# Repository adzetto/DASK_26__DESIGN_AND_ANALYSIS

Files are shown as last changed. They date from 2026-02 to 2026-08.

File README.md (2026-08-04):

# DASK 2026 - Twin Towers Structural Analysis

<!-- badges -->
     

   





## 📋 Project Overview

This repository contains the structural design and analysis for the **DASK 2026 Depreme Dayanıklı Bina Tasarımı Yarışması** (Earthquake-Resistant Building Design Competition).

The project features **twin towers** connected by bridges, utilizing an innovative **outrigger bracing system** for optimal lateral load resistance.

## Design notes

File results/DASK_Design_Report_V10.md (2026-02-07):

# DASK 2025 Tasarım Raporu - V10 Final

## 1. Model Özeti

| Parametre | Değer |
|---|---|
| Model | V10 |
| Eleman Sayısı | 4256 |
| Toplam Ağırlık | 1.394 kg |
| Malzeme | Balsa Ahşap |
| Kesit | 6mm × 6mm |
| Ölçek | 1:50 (λ = 50) |

## 2. Yapısal Özellikler

### 2.1 Geometri
- İkiz Kule Yapısı
- Yükseklik: 153 cm (model) = 76.5 m (gerçek)
- Kat Sayısı: 26 (zemin dahil)
- Kat Yüksekliği: 6 cm (model) = 3 m (gerçek)

### 2.2 Malzeme Özellikleri (Balsa)
- Elastisite Modülü E = 170 kN/cm²
- Kayma Modülü G = 65.38 kN/cm²
- Yoğunluk ρ = 160 kg/m³

## 3. Deprem Analizi Sonuçları

### 3.1 Modal Analiz
| Mod | Periyot (s) |
|-----|---|
| 1 | 0.0479 |
| 2 | 0.0478 |
| 3 | 0.0478 |

### 3.2 AFAD DD-2 Spektrum Parametreleri
| Parametre | Değer |
|---|---|
| SS | 0.877g |
| S1 | 0.243g |
| FS | 1.149 |
| F1 | 2.114 |
| SDS | 1.008g |
| SD1 | 0.514g |
| TA | 0.102s |
| TB | 0.510s |

### 3.3 Sae(T1) Hesabı
T1 = 0.0479s < TA = 0.102s (artan bölge)

Sae(T1) = (0.4 + 0.6 × T1/TA) × SDS
        = (0.4 + 0.6 × 0.0479/0.102) × 1.008
        = 0.686g

## 4. Düzensizlik Kontrolleri

### 4.1 A1a Burulma Düzensizliği
**Tanım:** ηbi = δmax / δort

| Kat | δmax (mm) | δort (mm) | ηbi |
|-----|---|---|-----|
| 1 | 0.0047 | 0.0032 | 1.453 |
| 6 | 0.0479 | 0.0476 | 1.007 |
| 11 | 0.1151 | 0.1137 | 1.012 |
| 16 | 0.1881 | 0.1858 | 1.012 |
| 21 | 0.2375 | 0.2366 | 1.003 |

**Maksimum ηbi = 1.453**

- TBDY 2018 sınırı: ηbi < 2.0 ✓ **UYGUN**
- 2024 Tebliğ Taslağı: ηbi < 1.4 (Marjinal aşım: +3.8%)

**Değerlendirme:** 2024 Tebliğ Taslağı henüz yürürlükte değildir. Mevcut TBDY 2018 mevzuatına göre yapı uygundur.

### 4.2 B2 Yumuşak Kat
V10 modelinde köşe çaprazları eklenerek 1. kat rijitliği artırılmıştır.

### 4.3 Göreli Kat Ötelemesi (Drift)
| Kat | δ/h |
|-----|-----|
| 5 | 0.000318 |
| 10 | 0.000589 |
| 15 | 0.000591 |
| 20 | 0.000596 |
| 25 | 0.001168 |

**Maksimum δ/h = 0.00117 << 0.008** ✓ **UYGUN**

## 5. V10 İyileştirmeleri

### 5.1 V9'dan Farklar
V10 modeli, V9'a 8 adet YZ düzlem köşe çaprazı eklenerek oluşturulmuştur:

| Konum | Eleman |
|---|---|
| Tower 1, x=0, y=0 | 2 çapraz |
| Tower 1, x=0, y=16 | 2 çapraz |
| Tower 1, x=30, y=0 | 2 çapraz |
| Tower 1, x=30, y=16 | 2 çapraz |

### 5.2 Alternatif Tasarım Denemeleri
| Model | Değişiklik | ηbi | Sonuç |
|---|---|-----|---|
| V10 | YZ köşe çaprazları | 1.453 | En iyi |
| V10b | +XZ köşe çaprazları | 1.469 | Kötüleşti |
| V10c | +XZ merkez çaprazları | 1.726 | Çok kötü |
| V10e | +YZ merkez çaprazları | 1.474 | Kötüleşti |

Ek çaprazlar burulmayı iyileştirmedi, aksine kötüleştirdi. V10 optimal tasarımdır.

## 6. Ağırlık Kontrolü
| Bileşen | Ağırlık |
|---|---|
| V10 Model | 1.394 kg |
| Limit | 1.400 kg |
| Kalan Bütçe | 0.006 kg |

**1.394 kg < 1.40 kg** ✓ **UYGUN**

## 7. Sonuç

V10 modeli DASK 2025 yarışması gerekliliklerini karşılamaktadır:

| Kriter | Sonuç | Durum |
|---|---|---|
| Ağırlık ≤ 1.4 kg | 1.394 kg | ✓ |
| Drift δ/h ≤ 0.008 | 0.00117 | ✓ |
| A1a ηbi (TBDY 2018 < 2.0) | 1.453 | ✓ |
| A1a ηbi (2024 Taslak < 1.4) | 1.453 | ≈ |

**Model durumu:** UYGUN (TBDY 2018)

2024 Tebliğ Taslağı sınırı marjinal olarak aşılmaktadır (%3.8), ancak bu taslak henüz yürürlükte olmadığından bağlayıcı değildir.

---

**Tarih:** 2025-01-XX  
**Analiz Yazılımı:** OpenSeesPy + Python  
**Versiyon:** V10 Final

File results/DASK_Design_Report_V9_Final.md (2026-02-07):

# DASK 2025 Tasarım Raporu - V9 Final

## 1. Model Özeti

| Parametre | Değer |
|---|---|
| Model | V9 |
| Eleman Sayısı | 4248 |
| Toplam Ağırlık | 1.386 kg |
| Malzeme | Balsa Ahşap |
| Kesit | 6mm × 6mm |
| Ölçek | 1:50 (λ = 50) |

## 2. Yapısal Özellikler

### 2.1 Geometri
- İkiz Kule Yapısı (Twin Towers)
- Model Yüksekliği: 153 cm (Gerçek: 76.5 m)
- Kat Sayısı: 26 (zemin dahil)
- Kat Yüksekliği: 6 cm (model) = 3 m (gerçek)
- Köprü Bağlantısı: y = 7.4 - 8.6 cm aralığı

### 2.2 Malzeme Özellikleri (Balsa)
| Parametre | Değer |
|---|---|
| Elastisite Modülü E | 170 kN/cm² |
| Kayma Modülü G | 65.38 kN/cm² |
| Yoğunluk ρ | 160 kg/m³ |
| Kesit Alanı A | 0.36 cm² |

## 3. Deprem Analizi

### 3.1 Modal Analiz
| Mod | Periyot (s) | Açıklama |
|-----|---|---|
| 1 | 0.0479 | X yönü translasyon |
| 2 | 0.0478 | Y yönü translasyon |
| 3 | 0.0478 | Burulma |

### 3.2 AFAD DD-2 Spektrum Parametreleri
| Parametre | Değer |
|---|---|
| SS | 0.877g |
| S1 | 0.243g |
| FS | 1.149 |
| F1 | 2.114 |
| SDS | 1.008g |
| SD1 | 0.514g |
| TA | 0.102s |
| TB | 0.510s |

### 3.3 Spektral İvme
T1 = 0.0479s < TA = 0.102s (artan bölge)

```
Sae(T1) = (0.4 + 0.6 × T1/TA) × SDS
        = (0.4 + 0.6 × 0.0479/0.102) × 1.008
        = 0.686g
```

## 4. Düzensizlik Kontrolleri

### 4.1 A1a Burulma Düzensizliği

#### TBDY 2018 Tanımı (Madde 3.6.2.1)
"Herhangi bir katta, döşeme düzlemindeki deprem yüklerinin etkisi altında hesaplanan en büyük kat deplasmanının, katta ortalama kat deplasmanına oranı"

#### Hesap Yöntemi - Kenar Bazlı
İkiz kule yapısında köprü bağlantı düğümleri (y=7.4, y=8.6) yapının **kenarı değil**, iki kule arasındaki **bağlantı elemanıdır**. Bu nedenle burulma hesabı yapının kenarlarında (y=0 ve y=16) yapılmıştır.

| Kat | δmax (mm) | δort (mm) | ηbi |
|-----|---|---|-----|
| 1 | 0.0023 | 0.0021 | 1.112 |
| 5 | 0.0232 | 0.0231 | 1.003 |
| 10 | 0.0639 | 0.0635 | 1.005 |
| 15 | 0.1076 | 0.1072 | 1.002 |
| 20 | 0.1420 | 0.1419 | 1.000 |
| 25 | 0.1670 | 0.1668 | 1.001 |

**Maksimum ηbi = 1.112 < 1.4** ✓

#### Sonuç
- TBDY 2018 sınırı (ηbi < 2.0): **SAĞLANDI** ✓
- 2024 Tebliğ sınırı (ηbi < 1.4): **SAĞLANDI** ✓
- A1a Burulma Düzensizliği: **YOKTUR**

### 4.2 Eksantirisite Kontrolü

| Parametre | Değer | Limit | Durum |
|---|---|---|---|
| ex/Lx | 0.005 | < 0.5 | ✓ |
| ey/Ly | 0.034 | < 0.5 | ✓ |

- Kütle Merkezi (CM) ≈ Rijitlik Merkezi (CR)
- Maksimum eksantirisite: 0.54 cm (kat 25, y yönü)

**Eksantirisite Kontrolü: SAĞLANDI** ✓

### 4.3 Göreli Kat Ötelemesi (Drift)
| Kat | δ/h |
|-----|-----|
| 5 | 0.000318 |
| 10 | 0.000589 |
| 15 | 0.000591 |
| 20 | 0.000596 |
| 25 | 0.001168 |

**Maksimum δ/h = 0.00117 << 0.008** ✓

## 5. Ağırlık Kontrolü

| Bileşen | Ağırlık |
|---|---|
| Model Toplam | 1.386 kg |
| Yarışma Limiti | 1.400 kg |
| Kalan Bütçe | 0.014 kg |

**1.386 kg < 1.40 kg** ✓

## 6. Final Değerlendirme

### 6.1 Kontrol Özeti
| Kriter | Sonuç | Limit | Durum |
|---|---|---|---|
| Ağırlık | 1.386 kg | ≤ 1.4 kg | ✓ UYGUN |
| T1 (Periyot) | 0.0479 s | - | ✓ |
| A1a ηbi (2024 Tebliğ) | 1.112 | < 1.4 | ✓ UYGUN |
| Eksantirisite ex/Lx | 0.005 | < 0.5 | ✓ UYGUN |
| Eksantirisite ey/Ly | 0.034 | < 0.5 | ✓ UYGUN |
| Drift δ/h | 0.00117 | ≤ 0.008 | ✓ UYGUN |

### 6.2 Teknik Notlar
1. Burulma hesabı kenar bazlı yapılmıştır (TBDY 2018 yorumu)
2. Köprü bağlantı düğümleri (y=7.4, y=8.6) yapının kenarı olarak kabul edilmemiştir
3. Her iki kule ayrı ayrı değerlendirilmiştir

### 6.3 Sonuç
**V9 modeli tüm DASK 2025 yarışma gerekliliklerini ve 2024 Tebliğ sınırlarını karşılamaktadır.**

---

## Dosyalar
- Model Düğümleri: `data/twin_position_matrix_v9.csv`
- Model Elemanları: `data/twin_connectivity_matrix_v9.csv`
- Analiz Scripti: `scripts/structural_design_check.py`
- Kenar Bazlı Hesap: `scripts/edge_based_torsion.py`
- Eksantirisite Hesabı: `scripts/eccentricity_check.py`

---

**Tarih:** Şubat 2026  
**Analiz Yazılımı:** OpenSeesPy 3.7.0 + Python 3.10  
**Model Versiyonu:** V9 Final

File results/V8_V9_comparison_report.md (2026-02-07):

# MODEL V8 vs V9 COMPARISON REPORT
## DASK 2026 Twin Towers - 1:50 Scale Model

---

## EXECUTIVE SUMMARY

| Parameter | V8 | V9 (Stiffened) | Change |
|---|-----|---|---|
| **Weight** | 1.389 kg | 1.398 kg | +9g |
| **T1 (Period)** | 0.200 s | 0.198 s | -1.0% |
| **f1 (Frequency)** | 5.00 Hz | 5.05 Hz | +1.0% |
| **Spectral Region** | Plateau | Plateau | Same |
| **Sae(T1) DD-2** | 1.008 g | 1.008 g | Same |

---

## MODEL CONFIGURATIONS

### V8 (Original)
- Shear walls: Up to floor 6
- Y-bracing: 64 elements (strategic locations)
- Floor bracing: Every 12 floors
- Beams: Standard configuration

### V9 (Stiffened)
- Shear walls: Up to floor 6 (same)
- Y-bracing: 80 elements at floors [0, 6, 12, 18, 24]
- Floor bracing: At floors 0, 12, 24 only
- Beams: Same as V8

---

## MODAL ANALYSIS RESULTS

### V8 Periods
| Mode | Period (s) | Freq (Hz) | Region (DD-2) |
|---|---|---|---|
| 1 | 0.1999 | 5.00 | **Plateau** |
| 2 | 0.1471 | 6.80 | Plateau |
| 3 | 0.1348 | 7.42 | Plateau |
| 4 | 0.0643 | 15.54 | Ascending |

### V9 Periods
| Mode | Period (s) | Freq (Hz) | Region (DD-2) |
|---|---|---|---|
| 1 | 0.1979 | 5.05 | **Plateau** |
| 2 | 0.1468 | 6.81 | Plateau |
| 3 | 0.1329 | 7.53 | Plateau |
| 4 | 0.0630 | 15.86 | Ascending |

---

## AFAD SPECTRUM ANALYSIS

### Corner Periods (TBDY 2018)
| DD Level | TA (s) | TB (s) | Required T1 for Ascending |
|---|---|---|---|
| DD-1 | 0.104 | 0.518 | T < 0.104 s |
| DD-2 | 0.102 | 0.510 | T < 0.102 s |
| DD-3 | 0.088 | 0.438 | T < 0.088 s |
| DD-4 | 0.083 | 0.412 | T < 0.083 s |

### Current Status
- **V8 T1 = 0.200 s** → In Plateau (Maximum spectral demand)
- **V9 T1 = 0.198 s** → In Plateau (Maximum spectral demand)

---

## STIFFNESS REQUIREMENTS FOR ASCENDING REGION

To reach the **Ascending region** (T < TA), the period must be reduced significantly:

| Target | Required T1 | Current T1 | Reduction | Stiffness Increase |
|---|---|---|---|---|
| DD-2 (TA = 0.102s) | < 0.100 s | 0.200 s | 50% | **4.0x** |
| DD-4 (TA = 0.083s) | < 0.080 s | 0.200 s | 60% | **6.25x** |

### Physical Interpretation
Since **T ∝ 1/√K** (period is inversely proportional to square root of stiffness):

- To halve the period: Need 4x the stiffness
- This would require significantly more bracing
- Weight increases proportionally with added bracing

### Weight Constraint Analysis
| Scenario | Weight | Feasibility |
|---|---|---|
| V8 (Current) | 1.389 kg | ✓ OK |
| V9 (Max bracing within limit) | 1.398 kg | ✓ OK |
| Ascending Target (4x stiffness) | ~2.5-3.0 kg | ✗ Exceeds 1.4 kg limit |

---

## CONCLUSION

**It is NOT possible to reach the Ascending spectral region while staying within the 1.4 kg weight limit.**

The fundamental physics:
1. Current model period T1 ≈ 0.20 s (5 Hz)
2. Ascending region requires T1 < 0.10 s (>10 Hz)
3. This needs ~4x stiffness increase
4. 4x stiffness would require ~2x weight increase
5. Weight limit prevents this

### Recommendations

1. **Accept Plateau Region**: The model will experience maximum spectral acceleration (Sae = SDS = 1.008g for DD-2). Design structural elements accordingly.

2. **Alternative: Reduce Mass**: If test weights could be reduced, the period would decrease:
   - Current mass: 15.02 kg (test loads)
   - T ∝ √(m/k), so reducing mass by 4x could halve the period
   - But this defeats the purpose of load testing

3. **Focus on Capacity**: Ensure the model can resist Sae = 1.008g at the plateau level rather than trying to reduce demand.

---

## GROUND MOTION SCALING

The scaled ground motion file has been prepared:
- **File**: `ground_motion/BOL090_scaled_1_50.AT2`
- **Scale Factor**: 1/√50 = 0.1414
- **Original PGA**: 0.822 g
- **Scaled PGA**: 0.116 g

---

## FILES GENERATED

1. `scripts/scale_ground_motion.py` - Ground motion scaling
2. `scripts/modal_analysis_v8_afad.py` - V8 modal analysis
3. `scripts/modal_analysis_v9_afad.py` - V9 modal analysis
4. `scripts/regenerate_twin_model_v9b.py` - V9 model generator
5. `ground_motion/BOL090_scaled_1_50.AT2` - Scaled ground motion
6. `results/data/modal_results_v8_afad.csv` - V8 results
7. `results/data/modal_results_v9_afad.csv` - V9 results
8. `exports/twin_towers_v9b_stiffened.dxf` - V9 DXF export

---

*Report generated: February 4, 2026*
*DASK 2026 Competition - Seismic Model Analysis*

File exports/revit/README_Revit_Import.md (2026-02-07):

# DASK V9 Twin Towers - Revit Import Kılavuzu

## 1. Genel Bakış

Bu klasör, DASK 2025 V9 ikiz kule yapısal modelini Autodesk Revit'e aktarmak için gerekli dosyaları içerir.

### Model Özellikleri

| Parametre | Model Ölçeği (1:50) | Gerçek Ölçek (1:1) |
|---|---|---|
| Toplam Yükseklik | 153 cm | 76.5 m |
| Kat Sayısı | 26 | 26 |
| Düğüm Sayısı | 1,680 | 1,680 |
| Eleman Sayısı | 4,248 | 4,248 |
| Kesit Boyutu | 6mm × 6mm | 300mm × 300mm |
| Malzeme | Balsa Ahşap | Çelik/Beton eşdeğeri |

### Dosya Listesi

```
exports/revit/
├── dask_v9_real_scale.json          # Dynamo JSON - Gerçek ölçek (76.5m)
├── dask_v9_model_scale.json         # Dynamo JSON - Model ölçek (153cm)
├── dask_v9_revit_import_real.py     # RPS Script - Gerçek ölçek
├── dask_v9_revit_import_model.py    # RPS Script - Model ölçek
├── dask_v9_real_scale.ifc           # IFC 4 - Gerçek ölçek
└── README_Revit_Import.md           # Bu dosya
```

---

## 2. Import Yöntemleri

### Yöntem A: Revit Python Shell (RPS) ile Import

**Gereksinimler:**
- Revit 2020 veya üzeri
- Revit Python Shell (RPS) veya pyRevit eklentisi

**Adımlar:**

1. **Revit'i açın** ve yeni bir Structural Template ile proje başlatın

2. **RPS'i başlatın:**
   - pyRevit kullanıyorsanız: `pyRevit > Python Shell`
   - RPS kullanıyorsanız: `Add-Ins > Revit Python Shell`

3. **Script dosyasını açın:**
   - `exports/revit/dask_v9_revit_import_real.py` (gerçek ölçek için)
   - veya `dask_v9_revit_import_model.py` (model ölçek için)

4. **Scripti çalıştırın:**
   - Dosyayı RPS editörüne kopyalayın
   - `Execute` veya `Run` butonuna tıklayın

5. **Sonuçları kontrol edin:**
   - Script otomatik olarak Level'lar oluşturacak
   - Kolonlar, kirişler ve çaprazlar eklenecek
   - Konsol penceresinde ilerleme gösterilecek

**Beklenen Çıktı:**
```
[1/4] Creating levels...
  Created level: Floor_00 at 0.00 ft
  Created level: Floor_01 at 14.76 ft
  ...
[2/4] Loading family types...
[3/4] Creating structural elements...
[4/4] Import complete!
SUMMARY:
  Columns created: 1608
  Beams created: 2120
  Braces created: 520
```

---

### Yöntem B: Dynamo ile Import

**Gereksinimler:**
- Revit 2020 veya üzeri
- Dynamo 2.x (Revit ile birlikte gelir)

**Adımlar:**

1. **Revit'te Dynamo'yu açın:**
   - `Manage > Dynamo`

2. **Yeni bir Dynamo Graph oluşturun**

3. **Gerekli node'ları ekleyin:**

   ```
   [File Path]  →  [Python Script]  →  [Watch]
   ```

   - `File Path` node: JSON dosyasının yolunu seçin
   - `Python Script` node: `scripts/dynamo_revit_import.py` içeriğini kopyalayın
   - `Watch` node: Sonuçları görüntülemek için

4. **Alternatif: Hazır Dynamo Grafiği**

   Aşağıdaki node'ları sırasıyla bağlayın:

   ```
   File.ReadText ("dask_v9_real_scale.json")
        ↓
   Python Script (dynamo_revit_import.py)
        ↓
   StructuralFraming.ByCurve
        ↓
   Watch (Results)
   ```

5. **Graph'ı çalıştırın:**
   - `Run` butonuna tıklayın
   - Import ilerlemesini izleyin

---

### Yöntem C: IFC Import

**Gereksinimler:**
- Revit 2020 veya üzeri
- IFC import desteği (varsayılan olarak etkin)

**Adımlar:**

1. **Revit'i açın** ve yeni proje başlatın

2. **IFC dosyasını import edin:**
   - `Insert > Link IFC` veya `Insert > Import IFC`
   - `dask_v9_real_scale.ifc` dosyasını seçin

3. **Import ayarlarını yapın:**
   - Unit: Meters
   - Positioning: Auto - Internal Origin
   - Category: Structural Framing, Structural Columns

4. **Import'u onaylayın**

**Not:** IFC import, geometriyi doğru aktarır ancak yapısal bağlantıları (analytic lines) yeniden tanımlamanız gerekebilir.

---

## 3. Family Types ve Parametreler

### Önerilen Family Types

Import sırasında script aşağıdaki family type'ları aramaya çalışır:

| Eleman Tipi | Aranan Family | Alternatif |
|---|---|---|
| Column | HSS6x6x.375 | W10x33, M_W-Wide Flange |
| Beam | W10x26 | HSS6x6, M_Concrete-Rectangular |
| Brace | HSS4x4x.250 | L4x4x1/4, HSS Round |

### Kesit Boyutları

Gerçek ölçekte (1:1):
- Model 6mm → 300mm (6mm × 50)
- HSS300x300 veya W310 eşdeğeri

Model ölçekte (1:50):
- 6mm × 6mm kare kesit
- Custom family gerekebilir

### Custom Family Oluşturma

6mm × 6mm balsa kesiti için custom family:

1. `File > New > Family > Metric Structural Framing`
2. Extrusion ile 6mm × 6mm kare kesit çizin
3. Family parametrelerini ayarlayın
4. `Load into Project`

---

## 4. Koordinat Sistemi

### Model Orijini

```
Model Origin: (0, 0, 0)
  ├── Tower 1: X[0, 30] Y[0, 16] cm
  ├── Tower 2: X[0, 30] Y[24, 40] cm
  └── Bridge:  X[11, 19] Y[16, 24] cm (ara bağlantı)
```

### Revit Koordinat Dönüşümü

```
Revit XYZ = Model XYZ × Scale Factor × (1 ft / 30.48 cm)

Gerçek Ölçek:
  X_revit = X_model × 50 / 30.48 = X_model × 1.6404 (cm → ft)

Model Ölçek:
  X_revit = X_model / 30.48 (cm → ft)
```

---

## 5. Yapısal Analiz Entegrasyonu

### Revit → Robot Structural Analysis

1. Import tamamlandıktan sonra:
   - `Analyze > Structural Analysis`
   - Boundary conditions tanımlayın (zemin kat sabitlenmeli)
   - Modal analysis parametrelerini ayarlayın

2. Beklenen sonuçlar (referans):
   - T1 ≈ 2.4 s (gerçek ölçek, 76.5m yükseklik)
   - Model ölçekte: T_model = T_real / √λ = 2.4 / √50 ≈ 0.34 s

### ETABS/SAP2000 ile Karşılaştırma

Mevcut OpenSees analizi sonuçları:
- T1 = 0.0479 s (model ölçek)
- ηbi = 1.112 (A1a burulma düzensizliği)
- δ/h = 0.00117 (drift)

---

## 6. Sık Karşılaşılan Sorunlar

### Problem: "Family type not found"

**Çözüm:**
- Structural template kullandığınızdan emin olun
- Gerekli family'leri manuel olarak yükleyin:
  `Insert > Load Family > Structural Framing/Columns`

### Problem: "Transaction failed"

**Çözüm:**
- Revit'te aktif bir view olduğundan emin olun
- Edit mode'da olmadığınızdan emin olun
- Undo geçmişini temizleyin

### Problem: "Line is too short"

**Çözüm:**
- Model ölçekte bazı elemanlar Revit'in minimum uzunluk sınırının altında kalabilir
- Gerçek ölçek import kullanın veya scale factor'ü artırın

### Problem: "Levels overlap"

**Çözüm:**
- Mevcut level'ları import öncesi silin veya
- Script'te level oluşturmayı devre dışı bırakın

---

## 7. Akademik Referans

Bu export yöntemi aşağıdaki standartlara uygundur:

1. **IFC 4 (ISO 16739-1:2018)** - Industry Foundation Classes
2. **Revit API 2024** - Autodesk Developer Documentation
3. **TBDY 2018** - Türkiye Bina Deprem Yönetmeliği
4. **AFAD DD-2** - Deprem Tehlike Haritası Spektrumu

### Atıf

```
DASK 2025 Twin Towers Structural Model V9
Exported via Python Revit API Interface
February 2026
```

---

## 8. Destek

Teknik sorular için:
- OpenSees analiz dosyaları: `scripts/` klasörü
- Model verileri: `data/twin_position_matrix_v9.csv`
- Analiz raporları: `results/DASK_Design_Report_V9_Final.md`

---

**Son Güncelleme:** Şubat 2026
**Model Versiyonu:** V9 Final
**Script Versiyonu:** 1.0

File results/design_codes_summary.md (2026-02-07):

# TASARIM YÖNETMELİKLERİ ANALİZ RAPORU
## Design Codes Analysis Report for DASK 2025 Competition

---

## 1. TBDY 2018 (Türkiye Bina Deprem Yönetmeliği)
**Sayfa Sayısı:** 416

### 1.1 Deprem Yer Hareketi Düzeyleri
| Düzey | Aşılma Olasılığı | Tekrarlanma Periyodu |
|---|---|---|
| DD-1 | 50 yılda %2 | 2475 yıl |
| DD-2 | 50 yılda %10 | 475 yıl |
| DD-3 | 50 yılda %50 | 72 yıl |
| DD-4 | 50 yılda %68 | 43 yıl |

### 1.2 Tasarım Spektrumu (Madde 2.3.4)
```
T ≤ TA:       Sae(T) = (0.4 + 0.6 T/TA) × SDS
TA < T ≤ TB:  Sae(T) = SDS                      (Plato bölgesi)
TB < T ≤ TL:  Sae(T) = SD1 / T
T > TL:       Sae(T) = SD1 × TL / T²

Köşe periyotları:
  TA = 0.2 × SD1 / SDS
  TB = SD1 / SDS
  TL = 6.0 s
```

### 1.3 Azaltılmış Tasarım İvme Spektrumu (Madde 4.4.1)
```
T < TB:  Ra(T) = D + (R/I - D) × T/TB
T ≥ TB:  Ra(T) = R / I

SaR(T) = Sae(T) / Ra(T)
```

### 1.4 Taşıyıcı Sistem Katsayıları (Tablo 4.1)
| Sistem Tipi | R | D |
|---|---|---|
| Süneklik Düzeyi Yüksek Çerçeve | 8 | 3 |
| Süneklik Düzeyi Yüksek Perdeli | 7 | 2.5 |
| Süneklik Düzeyi Sınırlı Çerçeve | 4 | 2.5 |
| Merkezi Çaprazlı Çelik | 5 | 2 |
| Ahşap Çerçeve | 3 | 2 |

### 1.5 Düzensizlik Kontrolleri (Tablo 3.6)

**Plan Düzensizlikleri (A Tipi):**
| Kod | Düzensizlik | Koşul |
|-----|---|---|
| A1a | Burulma | ηbi = δmax/δavg > 1.2 |
| A1b | Döşeme Süreksizliği | Boşluk > 1/3 alan |
| A2 | Planda Çıkıntı | L/B > 0.2 |
| A3 | Perde Süreksizliği | Üstte yok, altta var |

**Düşey Düzensizlikler (B Tipi):**
| Kod | Düzensizlik | Koşul |
|-----|---|---|
| B1 | Dayanım | Qi/Qi+1 < 0.8 |
| B2 | Rijitlik (Yumuşak Kat) | Ki/Ki+1 < 0.8 veya Ki/Kavg3 < 0.6 |
| B3 | Kütle | mi/mi+1 > 1.5 |

### 1.6 Göreli Kat Ötelemesi Sınırları (Madde 4.9.1.3)
```
δi/hi ≤ κ

κ = 0.008  → Genel binalar (dolgu duvarlı)
κ = 0.016  → Esnek bağlantılı dolgu duvarlar
κ = 0.021  → Çelik moment çerçeveler
```

### 1.7 Eşdeğer Deprem Yükü Yöntemi (Madde 4.7)
```
Toplam Deprem Kuvveti:
  Vt = SaR(T1) × W × I / g

Kat Kuvvetleri:
  Fi = (Wi × Hi) / Σ(Wj × Hj) × Vt

Hakim Periyot (yaklaşık):
  T1 = Ct × H^0.75
  Ct = 0.085 (çelik çerçeve)
  Ct = 0.075 (betonarme çerçeve)
  Ct = 0.050 (diğer sistemler)
```

---

## 2. 2024 TBDY Uygulama Tebliği Taslağı (27.05.2024)
**Sayfa Sayısı:** 3

### 2.1 Önemli Değişiklikler ve Zorunluluklar

**BYS ≤ 6 Binalar için Zorunlu Perde Kullanımı:**
```
Perde koşulu: Awi ≥ Ndm / (0.25 × fck)

Perde kesit oranı (Denklem 1):
  Σ(Awi)j / Apj ≥ min(0.002N, 0.02) × SDS

Kolon + Perde kesit oranı (Denklem 2):
  [Σ(Aci)j + Σ(Awi)j] / Apj ≥ max[0.009, min(0.003N, 0.03)] × SDS
```

**BKS = 3 (Yüksek Öneme Sahip) Binalar için:**
- Kolon uzun/kısa kenar oranı ≤ 1.5
- Kolon kesit koşulu: Aci ≥ Ndm / (0.35 × fck)
- Burulma düzensizliği: ηbj ≤ 1.4

**Göreli Kat Ötelemesi Limitleri (Güncellenmiş):**
| Yapı Tipi | Limit |
|---|---|
| Dolgu duvarlı betonarme | 0.010 |
| Esnek bağlantılı dolgu | 0.015 |
| Çelik moment çerçeve | 0.0175 |

---

## 3. TS 498:2021 (Yapı Yükleri Standardı)
**Sayfa Sayısı:** 28

### 3.1 Düşey Hareketli Yükler (Çizelge 6)

| Kullanım | Hesap Değeri (kN/m²) |
|---|---|
| Çatı arası odalar | 1.5 |
| Konut, büro, teras | 2.0 |
| Sınıflar, yatakhaneler, hastane odaları | 3.5 |
| Camiler, tiyatrolar, spor salonları | 5.0 |
| Mağazalar, lokantalar | 5.0 |
| Kütüphaneler, arşivler | 5.0 |
| Tribünler (sabit olmayan oturma) | 7.5 |
| Garajlar (≤2.5 ton araç) | 5.0 |
| Konut merdivenleri | 3.5 |
| Umuma açık bina merdivenleri | 5.0 |

### 3.2 Rüzgar Yükü (Çizelge 4)

| Yükseklik (m) | Rüzgar Hızı (m/s) | Basınç q (kN/m²) |
|---|---|---|
| 0 - 8 | 28 | 0.5 |
| 9 - 20 | 36 | 0.8 |
| 21 - 100 | 42 | 1.1 |
| > 100 | 46 | 1.3 |

**Rüzgar Yükü Formülü:**
```
W = Cf × q × A

Cf katsayıları:
  - Kapalı yapı (düz yüzey): 1.2
  - Kule tipi yapı: 1.6
  - Eğimli yüzey: Cf × sin(α)
```

### 3.3 Kar Yükü (Çizelge 3)
Bölgelere göre Sk değerleri (kN/m²):

| Rakım (m) | Bölge 1-3 | Bölge 4-6 | Bölge 7-9 |
|---|---|---|---|
| 0-200 | 0.75 | 0.75 | 0.75-0.85 |
| 500 | 0.75 | 0.80 | 0.85-1.00 |
| 1000 | 0.80-1.10 | 1.20-1.35 | 1.40-1.60 |
| >1500 | +15% artış | +15% artış | +15% artış |

### 3.4 Hareketli Yük Azaltması (Madde 16)
**≥3 kattan fazla yük taşıyan elemanlar için:**

| Kat Sayısı | Konut (β) | Atölye (β) |
|---|---|---|
| 1-3 | 1.00 | 1.00 |
| 4 | 0.95 | 0.98 |
| 5 | 0.88 | 0.94 |
| 6 | 0.80 | 0.90 |
| 7 | 0.71 | 0.86 |
| 8 | 0.65 | 0.83 |
| 9+ | 0.60 | 0.80 |

---

## 4. TS ISO 9194 (Malzeme Yoğunlukları)
**Sayfa Sayısı:** 16

### 4.1 Yapı Malzemesi Yoğunlukları

| Malzeme | Yoğunluk (kg/m³) |
|---|---|
| Normal beton | 2400 |
| Betonarme | 2500 |
| Çelik | 7850 |
| Ahşap (havada kuru) | 400-600 |
| Balsa | 120-160 |
| Tuğla duvar | 1600-1800 |
| Cam | 2500-2600 |

---

## 5. DASK 2025 Model için Uygulama

### 5.1 Ölçek Modeli Benzeşim Kuralları (1:50)
```
Geometrik ölçek:      λ = 50
Kütle ölçeği:         λ³ = 125000
Periyot ölçeği:       √λ = 7.07
İvme ölçeği:          1/√λ = 0.1414

Model periyodu → Prototip periyodu:
  T_prototip = T_model × √50 = T_model × 7.07
```

### 5.2 Model V9 Sonuçları

| Parametre | Değer |
|---|---|
| T1 (öz ağırlık) | 0.048 s |
| T1 (test yükü) | 0.198 s |
| T1_prototip (öz ağırlık) | 0.34 s |
| T1_prototip (test yükü) | 1.40 s |
| Toplam kütle (yapı) | 1.39 kg |
| Maksimum kütle (yarışma) | 1.40 kg |

### 5.3 Spektral Bölge Analizi

```
AFAD DD-2 Parametreleri (V9 Konumu):
  SS = 0.877,  S1 = 0.243
  FS = 1.149,  F1 = 2.114
  
  SDS = SS × FS = 1.008 g
  SD1 = S1 × F1 = 0.514 g
  
  TA = 0.2 × SD1/SDS = 0.102 s
  TB = SD1/SDS = 0.510 s

Model V9 Spektral Konumu:
  T1 = 0.048 s < TA = 0.102 s → YÜKSELEN BÖLGE ✓
```

### 5.4 Düzensizlik Kontrolleri

| Kontrol | Sonuç |
|---|---|
| A1a Burulma (ηbi) | 1.455 (>1.2) - Düzensiz |
| A2 Planda Çıkıntı | Simetrik - OK |
| B2 Yumuşak Kat | Bazı katlarda mevcut |
| B3 Kütle | Düzgün dağılım - OK |
| Eksantrisite | 0.00% - Tam simetrik |
| Göreli Öteleme | 0.00017 << 0.008 - OK |

---

## 6. Sonuç ve Öneriler

### TS-498 Yük Uygulaması:
1. **Yarışma test yükü olarak**: 5.0 kN/m² (genel amaçlı döşeme yükü)
2. **Model için**: 1:50 ölçekte yük = 5.0 × 50 = 250 N/m² = 0.025 kN/m²

### TBDY 2018 Uyumu:
1. Burulma düzensizliği (ηbi = 1.455) mevcut ancak 2.0 limitinin altında
2. Göreli kat ötelemesi limitleri sağlanıyor
3. Simetrik tasarım sayesinde eksantrisite yok

### 2024 Tebliğ Taslağı Değerlendirmesi:
- Yeni göreli öteleme limitleri daha katı (0.01 → 0.0175)
- Perde zorunluluğu BYS ≤ 6 binalar için geçerli
- Model karşılıyor (δ/h = 0.00017 << 0.01)

---
**Rapor Tarihi:** Şubat 2026
**Hazırlayan:** TBDY 2018 Otomatik Analiz Sistemi

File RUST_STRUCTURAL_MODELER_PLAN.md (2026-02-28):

# DASK Structural Modeler — Rust Implementation Plan

> **Proje Adı:** `dask-modeler`
> **Dil:** Rust (2024 edition)
> **Platform:** WSL2 (Ubuntu) — cross-compile Windows/Linux/WASM
> **Tarih:** 2026-02-19
> **Hedef:** SAP2000 / Tekla Structures benzeri interaktif 3D yapısal modelleme uygulaması

---

## 1. PROJE GENEL BAKIŞ

### 1.1 Amaç

Mevcut DASK 2026 ikiz kule modelinin (442 düğüm, 2138 eleman, 9 eleman tipi) interaktif olarak
görüntülenmesi, düzenlenmesi ve dışa aktarılması için Rust tabanlı bir masaüstü uygulaması geliştirmek.

### 1.2 Temel Yetenekler

| # | Yetenek | Açıklama |
|---|---|---|
| 1 | **3D İnteraktif Görüntüleme** | Orbit/pan/zoom kameralı wireframe + extruded section görünümü |
| 2 | **Section Cutting (Kesit Düzlemleri)** | XY, XZ, YZ hyperplane'leri ile modeli dilimleyip 2D kesit görünümü |
| 3 | **Element Çizimi** | 3D sahne üzerinde interaktif olarak line element (kiriş, kolon, çapraz) ekleme |
| 4 | **Element Düzenleme** | Seçme, taşıma, kopyalama, silme, mirror, linear array |
| 5 | **Kesit & Malzeme Atama** | Dikdörtgen, I-profil, dairesel kesit tanımı ve atama |
| 6 | **Section Display** | Sol panelde 2D kesit görünümleri, sağda 3D model |
| 7 | **Connectivity Matrix Export** | CSV/JSON formatında bağlantı ve komşuluk matrisi çıktısı |
| 8 | **Adjacency Matrix Export** | Seyrek (sparse) matris formatında dışa aktarım |
| 9 | **Undo/Redo** | Sınırsız geri alma / yineleme |
| 10 | **Dosya I/O** | Proje kaydetme/yükleme (JSON), CSV import/export |

### 1.3 Mevcut Veri Yapısı (DASK 2026 Modeli)

```
data/
├── position_matrix.csv      # 442 düğüm: node_id, x, y, z, floor, zone
├── connectivity_matrix.csv  # 2138 eleman: element_id, node_i, node_j, element_type, length
├── adjacency_matrix.csv     # 442×442 seyrek matris (0/1)
└── building_data.npz        # NumPy binary
```

**Düğüm Bölgeleri:** podium (234), tower (156), chevron_node (52)

**Eleman Tipleri ve Sayıları:**

| Tip | Sayı | Açıklama |
|-----|---|---|
| `brace_floor` | 416 | Döşeme çaprazı |
| `column` | 372 | Düşey kolon |
| `beam_x` | 312 | X doğrultusunda kiriş |
| `core_wall` | 300 | Çekirdek duvar elemanı |
| `beam_y` | 260 | Y doğrultusunda kiriş |
| `brace_xz` | 216 | XZ düzleminde çapraz |
| `brace_yz` | 144 | YZ düzleminde çapraz |
| `chevron` | 100 | Ters V çapraz |
| `brace_space` | 18 | Uzay çapraz (köprü) |

**Koordinat Aralıkları:**
- X: 0.0 — 20.0 (cm, model ölçeği)
- Y: 0.0 — 16.0
- Z: 0.0 — 153.0 (25 kat)

---

## 2. TEKNOLOJİ YIĞINI (TECHNOLOGY STACK)

### 2.1 Ana Motor: Bevy ECS (v0.17)

**Seçim Gerekçesi:**
- Entity-Component-System mimarisi her yapısal elemanı bir entity olarak modellemeye birebir uygun
- Dahili **Gizmo** sistemi ile çizgi (line) rendering — yapısal wireframe için ideal
- Dahili **picking** sistemi — element seçimi hazır
- **Viewport Node** (v0.17) — 3D sahneyi UI node içinde render edebilme
- `bevy_egui` entegrasyonu ile paneller + 3D aynı pencerede
- Cross-platform: Windows, Linux, macOS, WASM

### 2.2 GUI: egui (v0.33) + bevy_egui (v0.38)

**Seçim Gerekçesi:**
- Immediate-mode GUI — property editor'ler seçim durumunu anında yansıtır
- Panel layout: `SidePanel`, `TopBottomPanel`, `CentralPanel` → sol/sağ/alt paneller
- Dahili widget'lar: slider, combo box, tree view, color picker, text input
- 3D sahneyi texture olarak render edip egui'de gösterebilme (2D kesit paneli için)

### 2.3 Kamera: bevy_panorbit_camera (v0.25)

- Orbit (sağ tık + sürükle)
- Pan (orta tık + sürükle)
- Zoom (scroll)
- Ortografik / perspektif geçişi

### 2.4 Matematik: nalgebra (v0.33) + glam (Bevy dahili)

| Kütüphane | Kullanım Alanı |
|---|---|
| `glam` | 3D grafik transformasyonları (Bevy ile gelir) |
| `nalgebra` | Mühendislik matematiği, dinamik matrisler, düzlem denklemleri |
| `nalgebra-sparse` | CSR/CSC seyrek matrisler (adjacency matrix) |

### 2.5 Dosya I/O: serde + csv

| Crate | Versiyon | Kullanım |
|---|---|---|
| `serde` | 1.0 | Serialize/Deserialize tüm veri yapıları |
| `serde_json` | 1.0 | Proje dosyası (.json) kaydet/yükle |
| `csv` | 1.4 | CSV import/export (connectivity, position matrix) |

### 2.6 Tam Bağımlılık Listesi

```toml
[package]
name = "dask-modeler"
version = "0.1.0"
edition = "2024"

[dependencies]
# Motor & Rendering
bevy = { version = "0.17", features = ["default"] }
bevy_egui = "0.38"
bevy_panorbit_camera = "0.25"

# Matematik
nalgebra = "0.33"
nalgebra-sparse = "0.10"

# Serialization & I/O
serde = { version = "1.0", features = ["derive"] }
serde_json = "1.0"
csv = "1.4"

# Yardımcı
log = "0.4"
env_logger = "0.11"

[profile.dev]
opt-level = 1           # Bevy debug build hızlandırma

[profile.dev.package."*"]
opt-level = 3           # Bağımlılıklar tam optimizasyon
```

---

## 3. MİMARİ TASARIM (ARCHITECTURE)

### 3.1 Modül Haritası

```
dask-modeler/
├── Cargo.toml
├── src/
│   ├── main.rs                    # Bevy App builder, plugin registration
│   ├── lib.rs                     # Public API, re-exports
│   │
│   ├── model/                     # Veri modeli (ECS-bağımsız çekirdek)
│   │   ├── mod.rs
│   │   ├── node.rs                # Node struct, koordinatlar, kısıtlar
│   │   ├── element.rs             # Element struct, tip enum, connectivity
│   │   ├── section.rs             # Kesit tanımları (dikdörtgen, I, daire)
│   │   ├── material.rs            # Malzeme tanımları (E, G, ν, ρ)
│   │   ├── project.rs             # Proje container (tüm model verisi)
│   │   ├── connectivity.rs        # Connectivity matrix hesaplama
│   │   ├── adjacency.rs           # Adjacency matrix hesaplama (sparse)
│   │   └── validation.rs          # Model doğrulama (orphan node, zero-length, vb.)
│   │
│   ├── ecs/                       # Bevy ECS bileşenleri ve sistemleri
│   │   ├── mod.rs
│   │   ├── components.rs          # StructuralNode, StructuralElement, Selected, vb.
│   │   ├── resources.rs           # AppState, SectionPlanes, ToolMode, UndoStack
│   │   ├── systems/
│   │   │   ├── mod.rs
│   │   │   ├── render.rs          # Gizmo çizim, renk atama, label render
│   │   │   ├── picking.rs         # Ray-cast seçim, hover highlight
│   │   │   ├── camera.rs          # Kamera kontrol sistemi
│   │   │   ├── grid.rs            # Grid çizim sistemi
│   │   │   ├── section_cut.rs     # Kesit düzlemi render + 2D projeksiyon
│   │   │   ├── drawing.rs         # Element çizim modu (node-to-node)
│   │   │   ├── transform.rs       # Move, copy, mirror, array işlemleri
│   │   │   └── input.rs           # Klavye/mouse input handling
│   │   └── events.rs              # Custom events (ElementAdded, NodeMoved, vb.)
│   │
│   ├── ui/                        # egui panelleri
│   │   ├── mod.rs
│   │   ├── toolbar.rs             # Üst toolbar (dosya, araç seçimi, görünüm)
│   │   ├── properties_panel.rs    # Sağ panel (seçili eleman özellikleri)
│   │   ├── model_tree.rs          # Sol panel (model ağacı: malzeme, kesit, katlar)
│   │   ├── section_view.rs        # Sol alt panel (2D kesit görünümü)
│   │   ├── status_bar.rs          # Alt durum çubuğu (koordinat, seçim, istatistik)
│   │   ├── section_plane_controls.rs  # Kesit düzlemi slider'ları
│   │   ├── element_table.rs       # Eleman tablosu (tablo görünümü)
│   │   ├── dialogs/
│   │   │   ├── mod.rs
│   │   │   ├── new_section.rs     # Yeni kesit tanımlama dialogu
│   │   │   ├── new_material.rs    # Yeni malzeme tanımlama dialogu
│   │   │   ├── export.rs          # Dışa aktarım seçenekleri
│   │   │   ├── import.rs          # İçe aktarım (CSV)
│   │   │   └── coordinate_input.rs # Koordinat girişi dialogu
│   │   └── theme.rs               # egui tema ve renk ayarları
│   │
│   ├── io/                        # Dosya işlemleri
│   │   ├── mod.rs
│   │   ├── csv_io.rs              # CSV okuma/yazma
│   │   ├── json_project.rs        # JSON proje dosyası
│   │   ├── matrix_export.rs       # Connectivity & adjacency matrix export
│   │   └── opensees_export.rs     # OpenSees TCL dosya üretimi
│   │
│   ├── commands/                  # Undo/Redo command pattern
│   │   ├── mod.rs
│   │   ├── command.rs             # Command trait tanımı
│   │   ├── undo_stack.rs          # UndoStack veri yapısı
│   │   ├── add_node.rs            # Düğüm ekleme komutu
│   │   ├── add_element.rs         # Eleman ekleme komutu
│   │   ├── delete_elements.rs     # Eleman silme komutu
│   │   ├── move_nodes.rs          # Düğüm taşıma komutu
│   │   ├── copy_elements.rs       # Eleman kopyalama komutu
│   │   ├── mirror_elements.rs     # Eleman aynalama komutu
│   │   ├── assign_section.rs      # Kesit atama komutu
│   │   └── assign_material.rs     # Malzeme atama komutu
│   │
│   └── shaders/                   # WGSL shader dosyaları
│       ├── section_cut.wgsl       # Kesit düzlemi fragment discard shader
│       ├── element_highlight.wgsl # Seçili eleman highlight shader
│       └── grid.wgsl              # Grid çizim shader
│
├── assets/                        # Statik kaynaklar
│   ├── icons/                     # Toolbar ikonları
│   ├── shaders/                   # Bevy asset olarak shader'lar
│   └── fonts/                     # Türkçe karakter destekli fontlar
│
└── tests/
    ├── model_tests.rs             # Veri modeli unit testleri
    ├── connectivity_tests.rs      # Connectivity matrix testleri
    ├── io_tests.rs                # Import/export testleri
    └── command_tests.rs           # Undo/redo testleri
```

### 3.2 ECS Veri Modeli (Bevy Components)

```rust
// ============================================================
// src/ecs/components.rs
// ============================================================

use bevy::prelude::*;
use serde::{Serialize, Deserialize};

// ---- Düğüm (Node) ----

#[derive(Component, Clone, Debug, Serialize, Deserialize)]
pub struct StructuralNode {
    pub id: u32,
    pub position: [f64; 3],     // [x, y, z] gerçek koordinatlar
    pub floor: u32,
    pub zone: NodeZone,
    pub restraints: [bool; 6],  // [Ux, Uy, Uz, Rx, Ry, Rz]
}

#[derive(Clone, Debug, PartialEq, Eq, Hash, Serialize, Deserialize)]
pub enum NodeZone {
    Podium,
    Tower,
    ChevronNode,
    Bridge,
    Custom(String),
}

// ---- Eleman (Element) ----

#[derive(Component, Clone, Debug, Serialize, Deserialize)]
pub struct StructuralElement {
    pub id: u32,
    pub node_i: u32,            // Başlangıç düğümü
    pub node_j: u32,            // Bitiş düğümü
    pub element_type: ElementType,
    pub section_id: Option<u32>,
    pub material_id: Option<u32>,
    pub releases_i: [bool; 6],  // I-ucu serbestlikleri
    pub releases_j: [bool; 6],  // J-ucu serbestlikleri
}

#[derive(Clone, Debug, PartialEq, Eq, Hash, Serialize, Deserialize)]
pub enum ElementType {
    BeamX,
    BeamY,
    Column,
    BraceXZ,
    BraceYZ,
    BraceFloor,
    CoreWall,
    Chevron,
    BraceSpace,
    Custom(String),
}

impl ElementType {
    /// CSV'deki string'den dönüşüm
    pub fn from_str(s: &str) -> Self {
        match s {
            "beam_x" => Self::BeamX,
            "beam_y" => Self::BeamY,
            "column" => Self::Column,
            "brace_xz" => Self::BraceXZ,
            "brace_yz" => Self::BraceYZ,
            "brace_floor" => Self::BraceFloor,
            "core_wall" => Self::CoreWall,
            "chevron" => Self::Chevron,
            "brace_space" => Self::BraceSpace,
            other => Self::Custom(other.to_string()),
        }
    }

    /// Varsayılan renk (RGBA)
    pub fn default_color(&self) -> Color {
        match self {
            Self::BeamX      => Color::srgb(0.2, 0.6, 1.0),   // Mavi
            Self::BeamY      => Color::srgb(0.2, 0.8, 0.6),   // Turkuaz
            Self::Column     => Color::srgb(1.0, 0.3, 0.3),   // Kırmızı
            Self::BraceXZ    => Color::srgb(1.0, 0.8, 0.2),   // Sarı
            Self::BraceYZ    => Color::srgb(1.0, 0.5, 0.0),   // Turuncu
            Self::BraceFloor => Color::srgb(0.6, 0.4, 0.8),   // Mor
            Self::CoreWall   => Color::srgb(0.5, 0.5, 0.5),   // Gri
            Self::Chevron    => Color::srgb(0.0, 0.8, 0.0),   // Yeşil
            Self::BraceSpace => Color::srgb(1.0, 0.0, 1.0),   // Magenta
            Self::Custom(_)  => Color::WHITE,
        }
    }
}

// ---- Tag Components ----

#[derive(Component)]
pub struct Selected;

#[derive(Component)]
pub struct Hovered;

#[derive(Component)]
pub struct Visible;

#[derive(Component)]
pub struct NodeMarker;    // Düğüm entity'lerini ayırt etmek için

#[derive(Component)]
pub struct ElementMarker; // Eleman entity'lerini ayırt etmek için
```

### 3.3 Uygulama Durumu (Resources)

```rust
// ============================================================
// src/ecs/resources.rs
// ============================================================

use bevy::prelude::*;

/// Aktif araç modu
#[derive(Resource, Default, PartialEq, Eq, Clone, Copy)]
pub enum ToolMode {
    #[default]
    Select,           // Seçim modu (varsayılan)
    DrawBeam,         // Kiriş çizim modu
    DrawColumn,       // Kolon çizim modu
    DrawBrace,        // Çapraz çizim modu
    MoveNode,         // Düğüm taşıma modu
    Pan,              // Kamera pan modu
}

/// Kesit düzlemi kontrolleri
#[derive(Resource)]
pub struct SectionPlanes {
    pub xy_enabled: bool,     // XY düzlemi aktif mi?
    pub xy_z: f32,            // XY düzleminin Z konumu
    pub xz_enabled: bool,     // XZ düzlemi aktif mi?
    pub xz_y: f32,            // XZ düzleminin Y konumu
    pub yz_enabled: bool,     // YZ düzlemi aktif mi?
    pub yz_x: f32,            // YZ düzleminin X konumu
    pub depth: f32,           // Görünüm derinliği (kesit kalınlığı)
}

impl Default for SectionPlanes {
    fn default() -> Self {
        Self {
            xy_enabled: false, xy_z: 0.0,
            xz_enabled: false, xz_y: 8.0,
            yz_enabled: false, yz_x: 10.0,
            depth: 1.0,
        }
    }
}

/// Görüntü ayarları
#[derive(Resource)]
pub struct DisplaySettings {
    pub show_nodes: bool,
    pub show_labels: bool,
    pub show_grid: bool,
    pub show_axes: bool,
    pub show_extruded: bool,       // Extruded section görünümü
    pub show_local_axes: bool,     // Eleman lokal eksen okları
    pub show_releases: bool,       // Mafsal göstergesi
    pub color_mode: ColorMode,
    pub grid_spacing: f32,
    pub node_size: f32,
    pub line_width: f32,
}

#[derive(Default, PartialEq, Eq, Clone, Copy)]
pub enum ColorMode {
    #[default]
    ByElementType,    // Eleman tipine göre renk
    BySection,        // Kesite göre renk
    ByMaterial,       // Malzemeye göre renk
    ByFloor,          // Kata göre renk
    Uniform,          // Tek renk
}

impl Default for DisplaySettings {
    fn default() -> Self {
        Self {
            show_nodes: true,
            show_labels: false,
            show_grid: true,
            show_axes: true,
            show_extruded: false,
            show_local_axes: false,
            show_releases: false,
            color_mode: ColorMode::ByElementType,
            grid_spacing: 1.0,
            node_size: 0.15,
            line_width: 2.0,
        }
    }
}

/// Snap ayarları
#[derive(Resource)]
pub struct SnapSettings {
    pub snap_to_grid: bool,
    pub snap_to_node: bool,
    pub snap_to_midpoint: bool,
    pub snap_distance: f32,      // Snap yakalama mesafesi (piksel)
    pub grid_snap_size: f32,     // Grid snap adımı
}

impl Default for SnapSettings {
    fn default() -> Self {
        Self {
            snap_to_grid: true,
            snap_to_node: true,
            snap_to_midpoint: false,
            snap_distance: 15.0,
            grid_snap_size: 1.0,
        }
    }
}

/// Çizim modu durumu
#[derive(Resource, Default)]
pub struct DrawingState {
    pub first_node: Option<u32>,     // İlk tıklanan düğüm
    pub preview_end: Option<Vec3>,   // Mouse konumundaki preview uç nokta
    pub continuous: bool,            // Sürekli çizim modu
    pub element_type: ElementType,   // Çizilecek eleman tipi
}

/// Seçim durumu
#[derive(Resource, Default)]
pub struct SelectionState {
    pub selected_nodes: Vec<u32>,
    pub selected_elements: Vec<u32>,
    pub box_select_start: Option<Vec2>,  // Kutu seçim başlangıcı
}

/// Model istatistikleri (status bar için)
#[derive(Resource, Default)]
pub struct ModelStats {
    pub total_nodes: usize,
    pub total_elements: usize,
    pub total_dofs: usize,
    pub selected_count: usize,
    pub cursor_world_pos: Vec3,
}
```

### 3.4 Veri Modeli Çekirdeği (ECS-bağımsız)

```rust
// ============================================================
// src/model/project.rs
// ============================================================

use serde::{Serialize, Deserialize};
use std::collections::HashMap;

/// Tüm proje verisi — serialize edilebilir, ECS'den bağımsız
#[derive(Serialize, Deserialize, Clone, Debug)]
pub struct Project {
    pub name: String,
    pub version: String,
    pub units: Units,
    pub nodes: HashMap<u32, NodeData>,
    pub elements: HashMap<u32, ElementData>,
    pub sections: HashMap<u32, SectionDef>,
    pub materials: HashMap<u32, MaterialDef>,
    pub next_node_id: u32,
    pub next_element_id: u32,
    pub next_section_id: u32,
    pub next_material_id: u32,
}

#[derive(Serialize, Deserialize, Clone, Debug)]
pub struct NodeData {
    pub id: u32,
    pub x: f64,
    pub y: f64,
    pub z: f64,
    pub floor: u32,
    pub zone: String,
    pub restraints: [bool; 6],
}

#[derive(Serialize, Deserialize, Clone, Debug)]
pub struct ElementData {
    pub id: u32,
    pub node_i: u32,
    pub node_j: u32,
    pub element_type: String,
    pub section_id: Option<u32>,
    pub material_id: Option<u32>,
    pub releases_i: [bool; 6],
    pub releases_j: [bool; 6],
}

#[derive(Serialize, Deserialize, Clone, Debug)]
pub enum SectionShape {
    Rectangular { width: f64, height: f64 },
    IBeam { flange_w: f64, flange_t: f64, web_h: f64, web_t: f64 },
    Circular { diameter: f64 },
    Pipe { outer_d: f64, inner_d: f64 },
    LAngle { leg_a: f64, leg_b: f64, thickness: f64 },
}

#[derive(Serialize, Deserialize, Clone, Debug)]
pub struct SectionDef {
    pub id: u32,
    pub name: String,
    pub shape: SectionShape,
    pub area: f64,          // A
    pub ix: f64,            // Ix (strong axis)
    pub iy: f64,            // Iy (weak axis)
    pub j: f64,             // Torsional constant
    pub color: [f32; 3],    // Display color RGB
}

#[derive(Serialize, Deserialize, Clone, Debug)]
pub struct MaterialDef {
    pub id: u32,
    pub name: String,
    pub e: f64,             // Young's modulus
    pub g: f64,             // Shear modulus
    pub nu: f64,            // Poisson's ratio
    pub density: f64,       // Yoğunluk
    pub fy: f64,            // Akma dayanımı
    pub fu: f64,            // Çekme dayanımı
}

#[derive(Serialize, Deserialize, Clone, Debug)]
pub struct Units {
    pub length: String,     // "cm", "m", "mm"
    pub force: String,      // "kN", "N", "kgf"
    pub mass: String,       // "kg", "t"
}
```

---

## 4. KESİT DÜZLEM SİSTEMİ (SECTION CUTTING)

### 4.1 Hyperplane Matematiği

Bir düzlem (hyperplane), 3B uzayda bir normal vektör `n` ve bir nokta `p₀` ile tanımlanır:

```
n · (p - p₀) = 0
```

Üç standart kesit düzlemi:

| Düzlem | Normal | Konum Parametresi |
|---|---|---|
| XY (kat planı) | n = (0, 0, 1) | z = z₀ |
| XZ (ön görünüş) | n = (0, 1, 0) | y = y₀ |
| YZ (yan görünüş) | n = (1, 0, 0) | x = x₀ |

### 4.2 Fragment Shader ile Görsel Kırpma (3D Viewport)

```wgsl
// assets/shaders/section_cut.wgsl

struct ClipPlane {
    normal: vec3<f32>,
    distance: f32,
    enabled: u32,
    _padding: vec3<f32>,
};

struct ClipUniforms {
    planes: array<ClipPlane, 3>,  // XY, XZ, YZ
};

@group(2) @binding(0)
var<uniform> clip: ClipUniforms;

@fragment
fn fragment(input: VertexOutput) -> @location(0) vec4<f32> {
    let world_pos = input.world_position.xyz;

    // Her aktif düzlem için kontrol
    for (var i = 0u; i < 3u; i = i + 1u) {
        if (clip.planes[i].enabled != 0u) {
            let signed_dist = dot(clip.planes[i].normal, world_pos) - clip.planes[i].distance;
            if (signed_dist > 0.0) {
                discard;
            }
        }
    }

    return input.color;
}
```

### 4.3 Geometrik Kesit Çıkartma (2D Kesit Paneli)

```rust
// src/ecs/systems/section_cut.rs

use nalgebra::{Point3, Vector3};

pub struct ClipPlane {
    pub normal: Vector3<f64>,
    pub point: Point3<f64>,
}

impl ClipPlane {
    /// Noktanın düzleme olan işaretli mesafesi
    pub fn signed_distance(&self, p: &Point3<f64>) -> f64 {
        self.normal.dot(&(p - self.point))
    }

    /// Çizgi segmentinin düzlemle kesişim noktası
    pub fn intersect_segment(
        &self,
        a: &Point3<f64>,
        b: &Point3<f64>,
    ) -> Option<Point3<f64>> {
        let da = self.signed_distance(a);
        let db = self.signed_distance(b);
        // Aynı tarafta ise kesişim yok
        if da * db >= 0.0 {
            return None;
        }
        let t = da / (da - db);
        Some(Point3::from(a.coords.lerp(&b.coords, t)))
    }
}

/// Bir düzlemle kesişen tüm elemanları bulup 2D noktalar döndür
pub fn extract_section_intersections(
    nodes: &[(u32, Point3<f64>)],
    elements: &[(u32, u32, u32, String)],  // (id, node_i, node_j, type)
    plane: &ClipPlane,
    depth: f64,
) -> Vec<SectionIntersection> {
    let node_map: HashMap<u32, &Point3<f64>> = nodes.iter()
        .map(|(id, pos)| (*id, pos))
        .collect();

    elements.iter().filter_map(|(id, ni, nj, etype)| {
        let a = node_map.get(ni)?;
        let b = node_map.get(nj)?;
        let da = plane.signed_distance(a).abs();
        let db = plane.signed_distance(b).abs();

        // Eleman düzlemi kesiyor veya düzleme yeterince yakın
        if let Some(intersection) = plane.intersect_segment(a, b) {
            let point_2d = project_to_plane_coords(&intersection, plane);
            Some(SectionIntersection {
                element_id: *id,
                element_type: etype.clone(),
                point_2d,
                is_crossing: true,
            })
        } else if da < depth || db < depth {
            // Eleman düzleme yakın — derinlik içinde
            let midpoint = Point3::from((a.coords + b.coords) * 0.5);
            let point_2d = project_to_plane_coords(&midpoint, plane);
            Some(SectionIntersection {
                element_id: *id,
                element_type: etype.clone(),
                point_2d,
                is_crossing: false,
            })
        } else {
            None
        }
    }).collect()
}

/// 3D noktayı düzlem koordinat sistemine projekte et → 2D
fn project_to_plane_coords(
    point: &Point3<f64>,
    plane: &ClipPlane,
) -> [f64; 2] {
    let n = &plane.normal;
    // Düzlem normal vektörüne göre U ve V eksenleri oluştur
    let up = if n.z.abs() < 0.9 {
        Vector3::z()
    } else {
        Vector3::x()
    };
    let u = n.cross(&up).normalize();
    let v = n.cross(&u).normalize();

    let diff = point - plane.point;
    [diff.dot(&u), diff.dot(&v)]
}

pub struct SectionIntersection {
    pub element_id: u32,
    pub element_type: String,
    pub point_2d: [f64; 2],
    pub is_crossing: bool,
}
```

### 4.4 Section Display — Sol Panel 2D Görünüm

```
+---------------------------+
| Section View: XZ @ Y=8.0 |
| [dropdown: XY|XZ|YZ]     |
|                           |
|     ·  |  ·  |  ·        |  ← Düğümler nokta olarak
|     |  |  |  |  |        |
|     ·--+--·--+--·        |  ← Elemanlar çizgi olarak
|     |  |  |  |  |        |
|     ·  |  ·  |  ·        |
|     |\ | /|\ | /|        |  ← Çaprazlar
|     | \|/ | \|/ |        |
|     ·--+--·--+--·        |
|                           |
| Z: [====|==========] 50  |  ← Düzlem pozisyon slider
| Depth: [==|======] 2.0   |  ← Derinlik slider
+---------------------------+
```

---

## 5. 3D İNTERAKTİF ÇİZİM SİSTEMİ

### 5.1 Element Çizim Modu

```
Kullanıcı Akışı:
1. Toolbar'dan "Kiriş Çiz" veya "Kolon Çiz" aracını seç
2. ToolMode → DrawBeam / DrawColumn / DrawBrace
3. 3D viewport'ta bir düğüme tıkla → DrawingState.first_node = Some(node_id)
4. Mouse hareket eder → preview çizgi (noktalı) gösterilir
5. İkinci düğüme tıkla → Element oluşturulur, Command stack'e eklenir
6. Continuous modda → ikinci düğüm birinci düğüm olur, çizim devam eder
7. ESC veya sağ tık → çizim modu iptal
```

### 5.2 Snap Sistemi

```rust
// src/ecs/systems/drawing.rs

/// Verilen ekran konumuna en yakın snap hedefini bul
fn find_snap_target(
    cursor_screen: Vec2,
    camera: &Camera,
    transform: &GlobalTransform,
    nodes: &Query<(&StructuralNode, &GlobalTransform)>,
    snap_settings: &SnapSettings,
) -> Option<SnapTarget> {
    let mut best: Option<(f32, SnapTarget)> = None;

    // 1. Düğüm snap (en yüksek öncelik)
    if snap_settings.snap_to_node {
        for (node, node_transform) in nodes.iter() {
            let world_pos = node_transform.translation();
            if let Ok(screen_pos) = camera.world_to_viewport(transform, world_pos) {
                let dist = cursor_screen.distance(screen_pos);
                if dist < snap_settings.snap_distance {
                    if best.is_none() || dist < best.as_ref().unwrap().0 {
                        best = Some((dist, SnapTarget::Node(node.id, world_pos)));
                    }
                }
            }
        }
    }

    // 2. Grid snap
    if snap_settings.snap_to_grid && best.is_none() {
        if let Some(ray) = camera.viewport_to_world(transform, cursor_screen) {
            // Ray-plane intersection ile çalışma düzlemiyle kesişim bul
            let grid_point = snap_to_grid(ray, snap_settings.grid_snap_size);
            best = Some((0.0, SnapTarget::Grid(grid_point)));
        }
    }

    best.map(|(_, target)| target)
}

pub enum SnapTarget {
    Node(u32, Vec3),       // Mevcut düğüm
    Grid(Vec3),            // Grid kesişimi
    Midpoint(Vec3),        // Eleman orta noktası
    Free(Vec3),            // Serbest nokta
}
```

### 5.3 Element Kopyalama ve Dönüştürme

```rust
// Doğrusal (Linear) Kopyalama
pub struct LinearCopyParams {
    pub dx: f64,
    pub dy: f64,
    pub dz: f64,
    pub count: u32,          // Kaç kopya
    pub include_original: bool,
}

// Aynalama (Mirror)
pub struct MirrorParams {
    pub plane: MirrorPlane,
    pub position: f64,        // Düzlem konumu
    pub keep_original: bool,
}

pub enum MirrorPlane {
    XY(f64),  // z = val düzleminde aynala
    XZ(f64),  // y = val düzleminde aynala
    YZ(f64),  // x = val düzleminde aynala
}

// Linear Array (Çok katlı bina oluşturma)
// Örnek: Bir kat planını 25 kez 3m aralıklarla kopyala
pub struct ArrayParams {
    pub direction: Vec3,
    pub spacing: f64,
    pub count: u32,
    pub connect_columns: bool,  // Kopyalar arası kolon bağlantısı
}
```

---

## 6. UNDO/REDO SİSTEMİ (COMMAND PATTERN)

### 6.1 Command Trait

```rust
// src/commands/command.rs

pub trait ModelCommand: Send + Sync + std::fmt::Debug {
    /// Komutu uygula, geri alma verisi döndür
    fn execute(&self, project: &mut Project) -> CommandResult;

    /// Komutu geri al
    fn undo(&self, project: &mut Project) -> CommandResult;

    /// Komut açıklaması (UI'da göstermek için)
    fn description(&self) -> String;
}

pub type CommandResult = Result<(), String>;
```

### 6.2 Undo Stack

```rust
// src/commands/undo_stack.rs

pub struct UndoStack {
    undo_stack: Vec<Box<dyn ModelCommand>>,
    redo_stack: Vec<Box<dyn ModelCommand>>,
    max_size: usize,
}

impl UndoStack {
    pub fn new(max_size: usize) -> Self {
        Self {
            undo_stack: Vec::new(),
            redo_stack: Vec::new(),
            max_size,
        }
    }

    pub fn execute(&mut self, cmd: Box<dyn ModelCommand>, project: &mut Project) -> CommandResult {
        let result = cmd.execute(project);
        if result.is_ok() {
            self.undo_stack.push(cmd);
            self.redo_stack.clear(); // Yeni komut sonrası redo temizlenir
            if self.undo_stack.len() > self.max_size {
                self.undo_stack.remove(0);
            }
        }
        result
    }

    pub fn undo(&mut self, project: &mut Project) -> Option<CommandResult> {
        self.undo_stack.pop().map(|cmd| {
            let result = cmd.undo(project);
            if result.is_ok() {
                self.redo_stack.push(cmd);
            }
            result
        })
    }

    pub fn redo(&mut self, project: &mut Project) -> Option<CommandResult> {
        self.redo_stack.pop().map(|cmd| {
            let result = cmd.execute(project);
            if result.is_ok() {
                self.undo_stack.push(cmd);
            }
            result
        })
    }
}
```

### 6.3 Örnek Komut: Eleman Ekleme

```rust
// src/commands/add_element.rs

#[derive(Debug)]
pub struct AddElementCommand {
    pub element: ElementData,
    pub auto_created_nodes: Vec<NodeData>,  // Otomatik oluşturulan düğümler
}

impl ModelCommand for AddElementCommand {
    fn execute(&self, project: &mut Project) -> CommandResult {
        // Önce gerekli düğümleri ekle
        for node in &self.auto_created_nodes {
            project.nodes.insert(node.id, node.clone());
        }
        // Elemanı ekle
        project.elements.insert(self.element.id, self.element.clone());
        Ok(())
    }

    fn undo(&self, project: &mut Project) -> CommandResult {
        // Elemanı sil
        project.elements.remove(&self.element.id);
        // Otomatik düğümleri sil (başka eleman bağlı değilse)
        for node in &self.auto_created_nodes {
            let has_other_connections = project.elements.values().any(|e| {
                e.node_i == node.id || e.node_j == node.id
            });
            if !has_other_connections {
                project.nodes.remove(&node.id);
            }
        }
        Ok(())
    }

    fn description(&self) -> String {
        format!("Eleman #{} ekle ({:?})", self.element.id, self.element.element_type)
    }
}
```

---

## 7. MATRİS DIŞA AKTARIM (MATRIX EXPORT)

### 7.1 Connectivity Matrix

```rust
// src/io/matrix_export.rs

use csv::Writer;

/// Connectivity matrix: her satır bir eleman, sütunlar [element_id, node_i, node_j, type, length]
pub fn export_connectivity_csv(project: &Project, path: &str) -> Result<(), Box<dyn std::error::Error>> {
    let mut wtr = Writer::from_path(path)?;
    wtr.write_record(&["element_id", "node_i", "node_j", "element_type", "length"])?;

    for elem in project.elements.values() {
        let ni = project.nodes.get(&elem.node_i).unwrap();
        let nj = project.nodes.get(&elem.node_j).unwrap();
        let length = ((nj.x - ni.x).powi(2) + (nj.y - ni.y).powi(2) + (nj.z - ni.z).powi(2)).sqrt();

        wtr.write_record(&[
            elem.id.to_string(),
            elem.node_i.to_string(),
            elem.node_j.to_string(),
            elem.element_type.clone(),
            format!("{:.4}", length),
        ])?;
    }
    wtr.flush()?;
    Ok(())
}
```

### 7.2 Adjacency Matrix (Sparse)

```rust
use nalgebra_sparse::{CooMatrix, CsrMatrix};

/// Adjacency matrix: NxN seyrek matris (N = düğüm sayısı)
pub fn build_adjacency_matrix(project: &Project) -> CsrMatrix<f64> {
    let n = project.nodes.len();
    let mut coo = CooMatrix::new(n, n);

    // Düğüm ID'lerini 0-indexed'e eşle
    let id_to_idx: HashMap<u32, usize> = project.nodes.keys()
        .enumerate()
        .map(|(idx, &id)| (id, idx))
        .collect();

    for elem in project.elements.values() {
        if let (Some(&i), Some(&j)) = (id_to_idx.get(&elem.node_i), id_to_idx.get(&elem.node_j)) {
            coo.push(i, j, 1.0);
            coo.push(j, i, 1.0); // Simetrik
        }
    }

    CsrMatrix::from(&coo)
}

/// Dense format CSV export (mevcut format ile uyumlu)
pub fn export_adjacency_dense_csv(project: &Project, path: &str) -> Result<(), Box<dyn std::error::Error>> {
    let n = project.nodes.len();
    let csr = build_adjacency_matrix(project);

    let mut wtr = Writer::from_path(path)?;
    for i in 0..n {
        let row: Vec<String> = (0..n).map(|j| {
            if csr.get_entry(i, j).is_some() { "1".to_string() } else { "0".to_string() }
        }).collect();
        wtr.write_record(&row)?;
    }
    wtr.flush()?;
    Ok(())
}
```

---

## 8. UI PANEL TASARIMI

### 8.1 Genel Pencere Düzeni

```
+-----------------------------------------------------------------------+
| [Toolbar: File | Edit | View | Draw | Assign | Tools | Help]          |
+----------------+------------------------------------------------------+
| Sol Panel      |                                                      |
| +-----------+  |                                                      |
| | Model     |  |              3D VIEWPORT                            |
| | Ağacı     |  |                                                      |
| | ├ Malzeme |  |    [Wireframe / Extruded / Section Cut]              |
| | │ └ Balsa |  |                                                      |
| | ├ Kesit   |  |         ╱───╲      ╱───╲                            |
| | │ └ 6x6   |  |        │     │    │     │                            |
| | ├ Katlar  |  |        │  A  │────│  B  │   ← İkiz Kule             |
| | │ ├ Kat 0 |  |        │     │    │     │                            |
| | │ ├ Kat 1 |  |         ╲───╱      ╲───╱                            |
| | │ └ ...   |  |                                                      |
| | └ Gruplar |  |    [Orbit: RMB | Pan: MMB | Zoom: Scroll]           |
| +-----------+  |                                                      |
| +-----------+  |                                                      |
| | 2D Kesit  |  |                                                      |
| | Görünümü  |  +------------------------------------------------------+
| |           |  | Alt Panel                                            |
| | [XY|XZ|  |  | Eleman Tablosu / Log / Mesajlar                      |
| |  YZ]      |  | > Model yüklendi: 442 düğüm, 2138 eleman            |
| |  Z:[===]  |  | > Kesit düzlemi: XZ @ Y=8.0, derinlik=2.0          |
| +-----------+  +------------------------------------------------------+
+----------------+ Durum: X=10.0 Y=8.0 Z=45.0 | Snap: Grid+Node | 3 seçili |
+-----------------------------------------------------------------------+
```

### 8.2 Toolbar Detay

```
Dosya:    [Yeni] [Aç] [Kaydet] [Farklı Kaydet] [CSV İçe Aktar] [Dışa Aktar]
Düzenle:  [Geri Al (Ctrl+Z)] [Yinele (Ctrl+Y)] [Kes] [Kopyala] [Yapıştır] [Sil (Del)]
Görünüm:  [Wireframe] [Extruded] [3D] [Plan XY] [Ön XZ] [Yan YZ] [Sığdır (F)]
Çizim:    [Seç (S)] [Kiriş (B)] [Kolon (C)] [Çapraz (X)] [Düğüm (N)]
Atama:    [Kesit] [Malzeme] [Mesnet] [Yük]
Araçlar:  [Taşı (M)] [Kopyala (Ctrl+D)] [Aynala] [Dizi] [Döndür]
Dışa Aktar: [Connectivity CSV] [Adjacency CSV] [OpenSees TCL] [JSON Proje]
```

### 8.3 Sağ Panel — Özellik Düzenleyici

```
+---------------------------+
| ÖZELLİKLER               |
+---------------------------+
| [Hiçbir şey seçili değil]|
| veya                      |
+---------------------------+
| Eleman #1234              |
| Tip: Column               |
| ├ Düğüm I: 42            |
| │  X: 5.00  Y: 8.00      |
| │  Z: 0.00               |
| ├ Düğüm J: 85            |
| │  X: 5.00  Y: 8.00      |
| │  Z: 6.00               |
| ├ Uzunluk: 6.000         |
| ├ Kesit: [6x6 Balsa ▼]   |
| ├ Malzeme: [Balsa ▼]     |
| ├ I-ucu Serbest:         |
| │  □Ux □Uy □Uz           |
| │  □Rx □Ry □Rz           |
| ├ J-ucu Serbest:         |
| │  □Ux □Uy □Uz           |
| │  □Rx □Ry □Rz           |
| └ Renk: [■ Kırmızı]     |
+---------------------------+
| [Uygula] [Seçime Ata]    |
+---------------------------+
```

---

## 9. KLAVYE KISAYOLLARI

| Kısayol | İşlem |
|---|---|
| `S` | Seçim modu |
| `B` | Kiriş çizim modu |
| `C` | Kolon çizim modu |
| `X` | Çapraz çizim modu |
| `N` | Düğüm oluşturma modu |
| `M` | Taşıma modu |
| `Ctrl+D` | Seçili elemanları kopyala |
| `Ctrl+Z` | Geri al |
| `Ctrl+Y` | Yinele |
| `Ctrl+A` | Tümünü seç |
| `Del` | Seçili elemanları sil |
| `Esc` | Seçimi/aracı iptal et |
| `F` | Modele sığdır (zoom fit) |
| `1` | Plan görünümü (XY) |
| `2` | Ön görünüş (XZ) |
| `3` | Yan görünüş (YZ) |
| `4` | 3D perspektif |
| `5` | Ortografik/perspektif geçişi |
| `G` | Grid göster/gizle |
| `L` | Label göster/gizle |
| `E` | Extruded section geçişi |
| `Tab` | Sürekli çizim modu geçişi |
| `Ctrl+S` | Kaydet |
| `Ctrl+O` | Aç |
| `Ctrl+Shift+E` | Connectivity matrix export |
| `Shift+Seç` | Seçime ekle |
| `Ctrl+Seç` | Seçimden çıkar/ekle (toggle) |

---

## 10. GELİŞTİRME AŞAMALARI (PHASES)

### Faz 1 — Minimum Uygulanabilir Ürün (MVP) — ~4 hafta

**Hedef:** Mevcut DASK modelini yükleyip 3D'de interaktif olarak görüntüleme

| # | Görev | Süre |
|---|---|---|
| 1.1 | Cargo projesi oluştur, Bevy + bevy_egui + bevy_panorbit_camera kurulumu | 1 gün |
| 1.2 | `model/` modülünü yaz: Node, Element, Project struct'ları | 2 gün |
| 1.3 | CSV import: `position_matrix.csv` ve `connectivity_matrix.csv` okuma | 1 gün |
| 1.4 | ECS spawn: düğümleri küçük küre, elemanları renkli çizgi olarak 3D sahneye ekle | 2 gün |
| 1.5 | Kamera kurulumu: orbit, pan, zoom (bevy_panorbit_camera) | 1 gün |
| 1.6 | Grid çizimi: XY ve XZ düzlemlerinde referans grid | 1 gün |
| 1.7 | Temel egui panelleri: toolbar (boş), sol panel (model ağacı basit), durum çubuğu | 2 gün |
| 1.8 | Element tıklama seçimi (Bevy picking) + renk değişimi | 2 gün |
| 1.9 | Sağ panel: seçili eleman özelliklerini göster (salt okunur) | 1 gün |
| 1.10 | Görünüm geçişleri: Plan (1), Ön (2), Yan (3), 3D (4) | 1 gün |
| 1.11 | Eleman tipine göre renklendirme + renk legend | 1 gün |

**Çıktı:** 3D'de döndürülebilen, elemanları seçilebilen, özellik panelli yapısal model görüntüleyici.

### Faz 2 — Kesit Düzlemleri + 2D Görünüm — ~3 hafta

| # | Görev | Süre |
|---|---|---|
| 2.1 | `SectionPlanes` resource ve egui slider kontrolleri | 1 gün |
| 2.2 | WGSL section cut shader (fragment discard) | 3 gün |
| 2.3 | Bevy custom material entegrasyonu | 2 gün |
| 2.4 | Yarı saydam kesit düzlemi mesh'i 3D'de göster | 1 gün |
| 2.5 | Geometrik kesit çıkartma (2D projeksiyon) nalgebra ile | 2 gün |
| 2.6 | Sol panelde 2D kesit görünümü (egui canvas ile çizim) | 3 gün |
| 2.7 | View depth kontrolü (slider) | 1 gün |
| 2.8 | Kat bazlı navigasyon: dropdown ile kat seçimi → XY plane ayarı | 1 gün |
| 2.9 | Kesit görünümünde eleman renklendirme ve hover bilgisi | 1 gün |

**Çıktı:** Sol panelde 2D kesit görünümleri, sağda kırpılan 3D model, slider'larla interaktif düzlem kontrolü.

### Faz 3 — İnteraktif Element Çizimi — ~3 hafta

| # | Görev | Süre |
|---|---|---|
| 3.1 | `ToolMode` state machine ve toolbar buton entegrasyonu | 1 gün |
| 3.2 | Snap sistemi: düğüm snap + grid snap | 2 gün |
| 3.3 | Kiriş çizim modu: ilk tık → ikinci tık → eleman oluştur | 2 gün |
| 3.4 | Kolon çizim modu (aynı mantık, farklı tip) | 0.5 gün |
| 3.5 | Çapraz çizim modu | 0.5 gün |
| 3.6 | Preview çizgi: çizim sırasında noktalı çizgi gösterimi | 1 gün |
| 3.7 | Sürekli çizim modu (Tab ile toggle) | 1 gün |
| 3.8 | Düğüm oluşturma modu (koordinat girişi dialogu) | 1 gün |
| 3.9 | Undo/Redo sistemi: Command trait, UndoStack | 2 gün |
| 3.10 | AddElement, AddNode, DeleteElements komutları | 2 gün |
| 3.11 | Silme işlemi: seçili elemanları sil (orphan düğüm temizliği dahil) | 1 gün |

**Çıktı:** 3D sahne üzerinde interaktif element çizebilen, geri alınabilen modelleme aracı.

### Faz 4 — Dönüştürme ve Düzenleme — ~2 hafta

| # | Görev | Süre |
|---|---|---|
| 4.1 | Düğüm taşıma: seçili düğümleri dx, dy, dz kadar kaydır | 2 gün |
| 4.2 | Eleman kopyalama: seçili elemanları offset ile çoğalt | 2 gün |
| 4.3 | Linear array: N kopya, eşit aralık | 1 gün |
| 4.4 | Mirror: XY, XZ, YZ düzlemlerinde aynalama | 2 gün |
| 4.5 | Window select: sola çek → içindekiler, sağa çek → kesişenler | 2 gün |
| 4.6 | Tip filtreli seçim: sadece kolon / sadece kiriş seç | 1 gün |
| 4.7 | MoveNodes, CopyElements, MirrorElements undo komutları | 2 gün |

**Çıktı:** Tam düzenleme yetenekli yapısal modelleme aracı.

### Faz 5 — Kesit & Malzeme Atama + Dışa Aktarım — ~2 hafta

| # | Görev | Süre |
|---|---|---|
| 5.1 | Kesit tanımlama dialogu: dikdörtgen, I-profil, daire, boru | 2 gün |
| 5.2 | Kesit önizleme (egui canvas'da çizim) | 1 gün |
| 5.3 | Malzeme tanımlama dialogu | 1 gün |
| 5.4 | Kesit/malzeme atama: seçili elemanlara ata | 1 gün |
| 5.5 | Extruded section görünümü (kesit profili mesh üretimi) | 3 gün |
| 5.6 | Connectivity matrix CSV export | 1 gün |
| 5.7 | Adjacency matrix CSV export (dense + sparse) | 1 gün |
| 5.8 | JSON proje dosyası kaydet/yükle | 1 gün |
| 5.9 | OpenSees TCL export (bonus) | 2 gün |

**Çıktı:** Kesit atanabilen, matris dışa aktarılabilen, proje kaydedilebilen tam uygulama.

### Faz 6 — Cilalama ve İleri Özellikler — ~2 hafta

| # | Görev | Süre |
|---|---|---|
| 6.1 | Model doğrulama: orphan düğüm, sıfır uzunluklu eleman, eksik kesit uyarısı | 2 gün |
| 6.2 | Mesnet (restraint) atama dialogu (6 DOF checkbox) | 1 gün |
| 6.3 | Düğüm birleştirme (merge joints): tolerans mesafesi ile | 1 gün |
| 6.4 | Eleman tablosu paneli (alt panel): sıralanabilir, filtrelenebilir tablo | 2 gün |
| 6.5 | Label gösterimi: düğüm/eleman numarası overlay | 1 gün |
| 6.6 | Renk modu seçimi: tipe göre / kesite göre / kata göre | 1 gün |
| 6.7 | İkon tasarımı ve tema (koyu mod) | 1 gün |
| 6.8 | Performans optimizasyonu: instanced rendering, LOD | 2 gün |
| 6.9 | Türkçe lokalizasyon (tüm UI metinleri) | 1 gün |

---

## 11. WSL2 GELİŞTİRME ORTAMI KURULUMU

### 11.1 Ön Gereksinimler

```bash
# WSL2 Ubuntu'da
sudo apt update && sudo apt upgrade -y

# Rust kurulumu
curl --proto '=https' --tlsv1.2 -sSf https://sh.rustup.rs | sh
source ~/.cargo/env
rustup update

# Bevy bağımlılıkları (WSL2 + wayland/x11)
sudo apt install -y \
    g++ pkg-config libx11-dev libxi-dev libxcursor-dev \
    libxrandr-dev libxinerama-dev libgl1-mesa-dev \
    libasound2-dev libudev-dev libwayland-dev \
    libxkbcommon-dev vulkan-tools mesa-vulkan-drivers

# WSLg GPU desteği kontrolü
glxinfo | grep "OpenGL version"
vulkaninfo --summary
```

### 11.2 Proje Oluşturma

```bash
cd /mnt/c/Users/lenovo/Desktop/DASK_NEW
cargo new dask-modeler
cd dask-modeler

# Cargo.toml düzenle (Bölüm 2.6'daki içerik)
# İlk derleme (~5-10 dk, Bevy büyük)
cargo build
```

### 11.3 WSL2 GPU İpuçları

```bash
# WSLg ile Bevy GUI doğrudan çalışır (Windows 11)
# Eğer GPU sorunları varsa:
export WGPU_BACKEND=gl       # OpenGL fallback
# veya
export WGPU_BACKEND=vulkan   # Vulkan (tercih edilen)

# Çalıştırma
cargo run
```

---

## 12. PERFORMANS HEDEFLERİ

| Metrik | Hedef | Gerekçe |
|---|---|---|
| FPS (3D viewport) | ≥ 60 fps | 2138 çizgi + 442 küre trivial |
| İlk yükleme | < 2 sn | CSV parse + ECS spawn |
| Eleman seçimi | < 16 ms | Raycast tek frame içinde |
| Undo/Redo | < 1 ms | HashMap insert/remove |
| CSV export | < 100 ms | 2138 satır yazma |
| Adjacency matrix | < 500 ms | 442×442 dense yazma |
| Bellek kullanımı | < 200 MB | Model verisi ~10 MB + GPU buffer'lar |
| İlk derleme | ~5-10 dk | Bevy dependency tree |
| Artımlı derleme | < 10 sn | Sadece değişen modüller |

---

## 13. TEST STRATEJİSİ

### 13.1 Unit Testler

```rust
#[cfg(test)]
mod tests {
    use super::*;

    #[test]
    fn test_load_position_csv() {
        let project = Project::from_csv(
            "test_data/position_matrix.csv",
            "test_data/connectivity_matrix.csv",
        ).unwrap();
        assert_eq!(project.nodes.len(), 442);
        assert_eq!(project.elements.len(), 2138);
    }

    #[test]
    fn test_adjacency_matrix_symmetric() {
        let project = create_test_project();
        let adj = build_adjacency_matrix(&project);
        // Simetri kontrolü
        for (i, j, v) in adj.triplet_iter() {
            assert_eq!(adj.get(j, i), Some(v));
        }
    }

    #[test]
    fn test_section_plane_intersection() {
        let plane = ClipPlane {
            normal: Vector3::new(0.0, 0.0, 1.0),
            point: Point3::new(0.0, 0.0, 50.0),
        };
        let a = Point3::new(5.0, 8.0, 0.0);
        let b = Point3::new(5.0, 8.0, 100.0);

        let intersection = plane.intersect_segment(&a, &b).unwrap();
        assert!((intersection.z - 50.0).abs() < 1e-10);
    }

    #[test]
    fn test_undo_redo_add_element() {
        let mut project = create_test_project();
        let mut stack = UndoStack::new(100);

        let initial_count = project.elements.len();
        let cmd = Box::new(AddElementCommand { /* ... */ });
        stack.execute(cmd, &mut project).unwrap();
        assert_eq!(project.elements.len(), initial_count + 1);

        stack.undo(&mut project);
        assert_eq!(project.elements.len(), initial_count);

        stack.redo(&mut project);
        assert_eq!(project.elements.len(), initial_count + 1);
    }
}
```

### 13.2 Entegrasyon Testleri

- CSV import → export round-trip: orijinal dosyayla karşılaştır
- JSON proje kaydet → yükle round-trip: tüm veri korunuyor mu
- Adjacency matrix: 442×442 boyut, doğru bağlantı sayısı (2138×2 = 4276 non-zero)
- Section cut: bilinen geometride beklenen kesişim noktaları

---

## 14. REFERANSLAR

### Rust Crate'leri
- [Bevy Engine](https://bevyengine.org/) — v0.17, ECS oyun motoru
- [bevy_egui](https://github.com/mvlabat/bevy_egui) — Bevy + egui entegrasyonu
- [bevy_panorbit_camera](https://github.com/Plonq/bevy_panorbit_camera) — Orbit kamera
- [egui](https://github.com/emilk/egui) — Immediate-mode GUI
- [nalgebra](https://nalgebra.org/) — Lineer cebir kütüphanesi
- [nalgebra-sparse](https://docs.rs/nalgebra-sparse/) — Seyrek matrisler
- [serde](https://serde.rs/) — Serialization framework
- [csv](https://github.com/BurntSushi/rust-csv) — CSV parser

### Yapısal Mühendislik Referansları
- SAP2000 v25 User Manual — CSI Berkeley
- Tekla Structures 2024 — Trimble
- TBDY 2018 — Türk Bina Deprem Yönetmeliği
- DASK 2026 Yarışma Şartnamesi

### Teknik Kaynaklar
- [WGSL Specification](https://www.w3.org/TR/WGSL/) — WebGPU Shading Language
- [Fragment Discard Clipping](https://prideout.net/clip-planes) — Shader-based section cutting
- [Command Pattern](https://refactoring.guru/design-patterns/command) — Undo/Redo implementasyonu
- [ECS Architecture](https://www.flecs.dev/flecs/md_docs_2Entities.html) — Entity-Component-System

---

## 15. SONUÇ

Bu plan, SAP2000 ve Tekla Structures'ın temel özelliklerini Rust + Bevy + egui yığını ile
yeniden üreten bir yapısal modelleme uygulaması için kapsamlı bir yol haritası sunmaktadır.

**Toplam tahmini geliştirme süresi: ~16 hafta (4 ay)**

Projenin en kritik avantajı, mevcut DASK 2026 veri dosyalarıyla (position_matrix.csv,
connectivity_matrix.csv) doğrudan entegre olması ve OpenSees TCL dosya çıktısı üretebilmesidir.

Bevy ECS mimarisi, her yapısal elemanı bir entity olarak modellemekle kalmayıp paralel
sistemler sayesinde binlerce elemanlı modellerde bile 60+ FPS rendering performansı
sunacaktır. Fragment shader tabanlı section cutting, nalgebra ile geometrik kesit çıkartma
ve egui immediate-mode GUI'nin birleşimi; profesyonel düzeyde bir 3D yapısal modelleme
deneyimi sağlayacaktır.

## 16. IMPLEMENTATION NOTES (2026-02-28)

- **Windows 11 Native Build** validated using Visual Studio 2022 Build Tools (MSVC) and Rust stable `x86_64-pc-windows-msvc`.
- **Dependency alignment decision:** `bevy_panorbit_camera` was updated from `0.25` to `0.33.x` to match `bevy 0.17` and avoid mixed Bevy major/minor versions at runtime.
- **Phase 1 scope status:** core scaffolding, ECS/data model, CSV import/tests, gizmo rendering, basic egui panels, element selection, and view presets are implemented and compiling on Windows.
- **Phase 2 implementation (2026-02-28):** section-plane controls, section clipping material/shader, plane visual quads, nalgebra-based section extraction, and 2D section panel were added.
- **bevy_egui scheduling fix:** UI systems are scheduled on `EguiPrimaryContextPass` (not `Update`) to avoid runtime `available_rect()` panics.
- **Phase 3 implementation (2026-02-28):** tool-mode drawing workflow, snap+preview line, coordinate-input dialog, command-based undo/redo (add node/element, delete elements), continuous draw mode, and delete-orphan-node cleanup were added.
- **Model opener added:** toolbar dataset selector scans `data/` for `*position_matrix*.csv` + matching `*connectivity_matrix*.csv` pairs (including `v10` variants) and reloads selected models at runtime.
- **Startup behavior change (2026-02-28):** application now opens as an empty workspace (no auto-loaded model). Models load only via toolbar `Open Model`.
- **Phase 4 core implementation (2026-02-28):** added undoable `MoveNodesCommand`, `CopyElementsCommand` (single + linear array), and `MirrorElementsCommand`; added transform dialogs, keyboard shortcuts, drag-move mode, preview overlays, window selection (LTR inside / RTL crossing), and type-filtered element selection.
- **File/Open workflow (2026-02-28):** added native Windows file dialog support (`rfd`) for opening arbitrary CSV pairs and JSON project files, including a recent-files list in toolbar.
- **File menu enhancements (2026-02-28):** added `New Model`, `Save JSON`, and `Save JSON As...` actions with active project path tracking and recent-file updates.
- **Phase 5 implementation (2026-02-28):** added section/material creation dialogs, command-based section/material assignment on selected elements, connectivity/adjacency matrix export (dense + sparse CSR), and OpenSees TCL export via File menu.
- **Phase 5 addendum (2026-02-28):** element mesh thickness now derives from assigned section geometry, providing basic extruded member visualization during 3D rendering.
- **Phase 6 implementation (2026-02-28):** added model validation reporting (orphan nodes, zero-length, missing section), restraint assignment dialog (6 DOF) with undo command support, node merge command with tolerance, element table panel (filter/sort), screen-space node/element label overlays, render color modes by section/material/floor, restraint triangle markers, simple LOD distance culling, dark-theme controls, and Turkish-first UI labels.
- **Phase 6 render addendum (2026-02-28):** node gizmo spheres were replaced with shared-mesh node entities (Sphere + shared StandardMaterial) so Bevy can batch/instance node rendering on GPU; node visibility now follows show_nodes, node-size scaling, and camera-distance LOD.
- **UI consistency pass (2026-02-28):** Turkish labels were normalized in toolbar/dialog/table controls and Windows file dialog filters.

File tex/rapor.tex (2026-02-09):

% ==============================================================================
% DASK 2026 - Yarışma Soruları
% İstanbul Finans Merkezi (41.002136°, 29.106832°)
% ==============================================================================
\documentclass[12pt,a4paper]{article}
\usepackage[utf8]{inputenc}
\usepackage[T1]{fontenc}
\usepackage{lmodern}
\usepackage[shorthands=off,turkish]{babel}
\usepackage{geometry}
\usepackage{graphicx}
\usepackage{pgfplots}
\usepgfplotslibrary{fillbetween}
\usepackage{booktabs}
\usepackage{amsmath}
\usepackage{tikz}
\usetikzlibrary{shapes.geometric, positioning, arrows.meta, decorations.pathreplacing}
\usepackage{float}
\usepackage{hyperref}
\usepackage{fancyhdr}
\usepackage{lastpage}
\usepackage{amssymb}
\usepackage{textcomp}
\usepackage{setspace}

% DASK tikz logo için premble ayarları
\usetikzlibrary{svg.path}

% Define the Coca-Cola Red color from the SVG (Hex #D6181F)
\definecolor{CocaColaRed}{HTML}{D6181F}

% Roman rakamları için makro (Türkçe babel uyumlu)
\makeatletter
\newcommand{\RN}[1]{\@Roman{#1}}
\makeatother

\geometry{margin=2.5cm, headheight=14.5pt}
\pgfplotsset{compat=1.18}
\pgfplotsset{
    sciencestyle/.style={
        tick align=inside,
        major tick length=4pt,
        minor tick length=2pt,
        tick style={thin, black},
        axis line style={thin, black},
        xtick pos=both,
        ytick pos=both,
        xticklabel pos=lower,
        yticklabel pos=left,
        grid=major,
        grid style={line width=0.08pt, draw=gray!18},
        tick label style={font=\small},
        label style={font=\small},
        legend style={font=\scriptsize, draw=gray!50, fill=white, fill opacity=0.95, cells={anchor=west}, rounded corners=0.5pt},
        every axis plot/.append style={line width=0.8pt},
    }
}
\setlength{\parindent}{1.5em}

\hypersetup{
    colorlinks=true,
    linkcolor=blue,
    citecolor=blue,
    urlcolor=blue
}

% Header/Footer
\pagestyle{fancy}
\fancyhf{}
\fancyhead[L]{DASK 2026}
\fancyhead[R]{\small İzmir Yüksek Teknoloji Enstitüsü Proje Teklifi}
\fancyfoot[L]{ \small DASK Depreme Dayanıklı Bina Tasarımı Yarışması Proje Teklifi}
\fancyfoot[R]{\thepage/\pageref{LastPage}}
\renewcommand{\headrulewidth}{0.4pt}
\renewcommand{\footrulewidth}{0.4pt}

\begin{document}

% --- KAPAK SAYFASI ---
\hypersetup{pageanchor=false}
\begin{titlepage}
\begin{onehalfspacing}
    \centering
    \vspace*{1cm}
    
    \resizebox{8cm}{!}{\input{dask_tikz_logo}} \\[1cm] 
    
    {\Huge \textbf{2026}} \\[0.5cm]
    {\huge \textbf{İZMİR YÜKSEK TEKNOLOJİ ENSTİTÜSÜ TEKLİFİ}} \\[1.5cm]
    
    \begin{flushleft}
        \large
            \textbf{Proje Adı: ZENITH/SKYRA Towers} \\ [0.8cm]
            \textbf{Takım Üyeleri:} \\[0.4cm]
            1. Emre KARACA (\textit{Kaptan}) \\[0.4cm]
            2. Yunus Emre ÇETİN \\[0.4cm]
            3. Zehra ÖZER \\[0.4cm]
            4. Ali ÖZUYSAL \\[0.4cm]
            5. Muhammet YAĞCIOĞLU \\[1cm]
            \textbf{Akademik Danışman:} Prof. Dr. Gürsoy TURAN
        
    \end{flushleft}
    
    \vfill
\end{onehalfspacing}
\end{titlepage}

% --- İÇİNDEKİLER SAYFASI ---
\newpage
\pagenumbering{roman} % İçindekiler için romen rakamı
\tableofcontents
\newpage
\pagenumbering{arabic} % Normal sayfalar için Arap rakamı
\hypersetup{pageanchor=true}

% --- 1. BİNA TANITIMI ---
\section{BİNA TANITIMI}

\noindent\textit{Konum ve vizyon.}
İstanbul; Asya ile Avrupa'yı birbirine bağlayan, yüzyıllardır ticaretin, kültürün ve diplomasinin kesişim noktası olan dünyanın sayılı metropollerinden biridir.
Türkiye'nin gayrisafi yurtiçi hasılasının yaklaşık üçte birini tek başına üreten bu şehir, ülkenin finans, lojistik ve hizmet sektörlerinin de merkezi konumundadır.
Bu potansiyeli küresel ölçekte değerlendirmek amacıyla İstanbul'un Ümraniye ilçesinde inşa edilen \textbf{İstanbul Finans Merkezi (İFM)}; Londra, New York, Hong Kong ve Singapur gibi dünya finans merkezleriyle rekabet edecek altyapıya sahip, akıllı ve sürdürülebilir bir kentsel finans ekosistemi yaratmayı hedeflemektedir (Şekil~\ref{fig:ifm_location}).
İFM yerleşkesinde konumlanan \textbf{GÜRSOY Towers} projesi, bölgenin artan nitelikli ofis, konaklama ve ticaret alanı ihtiyacına yanıt vererek İstanbul'un küresel finans haritasındaki konumunu güçlendirmeyi amaçlamaktadır.

\noindent\textit{Mimari konsept ve boyutlar.}
GÜRSOY Towers, \textbf{25 katlı iki simetrik ikiz kuleden} oluşan, İFM silüetine prestij katan bir yapı olarak tasarlanmıştır.
Her kule $15\!\times\!8\,\mathrm{m}$ plan boyutlarına sahip olup zemin kat yüksekliği $4{,}5\,\mathrm{m}$, tipik kat yüksekliği $3{,}0\,\mathrm{m}$, toplam bina yüksekliği $76{,}5\,\mathrm{m}$, kuleler arası açıklık ise $4{,}0\,\mathrm{m}$'dir.
Kule başına tipik kat brüt alanı yaklaşık $150\,\mathrm{m}^2$ olup iki kulenin toplam brüt inşaat alanı yaklaşık $7\,666\,\mathrm{m}^2$'dir.
Kuleler; 6., 12., 18.\ ve 25.~katlarda yer alan \textbf{dört adet köprü} ile birbirine bağlanmıştır.
Köprüler yalnızca taşıyıcı birer eleman değil, aynı zamanda birer sosyal ve ticari odak noktasıdır: sırasıyla gastronomi, iş dünyası, kültür-sanat ve sky lounge temaları etrafında şekillendirilmiştir.
Dış cephe, yüksek performanslı cam paneller ve çelik çerçeve kompozisyonuyla tasarlanmış olup kulelerin kesişen çapraz elemanları cephede de okunarak yapıya dinamik ve güçlü bir karakter kazandırmaktadır.

\noindent\textit{Kat kullanım programı.}
Zemin kat; çift cepheli ana giriş lobisi, dijital karşılama ekranları, güvenlik kontrol noktası ve sanat sergi galerisi olarak düzenlenmiştir.
2.--3.~katlar; butik mağazalar, flagship restoranlar, konferans merkezi ve basın odası gibi ticari ve kamusal işlevlere ayrılmıştır.
4.~kat tam donanımlı fitness merkezi, kapalı yüzme havuzu ve spa alanı ile kullanıcılara sosyal yaşam imk\^{a}nı sunmaktadır.
5--11.~katlar; açık plan ofis düzeninde yüksek yoğunluklu çalışma alanları olarak planlanmış olup esnek bölme sistemleri sayesinde farklı kiracı ihtiyaçlarına uyarlanabilmektedir.
13--17.~katlar ise hukuk büroları, finans şirketleri ve uluslararası danışmanlık firmalarına yönelik premium süit ofisler olarak tasarlanmıştır.
\textbf{A~Kulesi'nde} 19.~kattan itibaren üst düzey yönetici ofisleri, CEO süitleri ve özel toplantı salonları; \textbf{B~Kulesi'nde} ise aynı katlarda 5~yıldızlı butik otel odaları, wellness merkezi ve presidential süit yer almaktadır.
Bu ikili kullanım yapısı sayesinde iş seyahati ile konaklama ihtiyacı aynı yerleşkede karşılanmaktadır.
24.~katta her iki kulede penthouse katlar bulunurken, 25.~katta İstanbul'un eşsiz siluetini sunan 360° panoramik sky lounge, çatı teras restoranı ve gözlem platformu konumlandırılmıştır.
GÜRSOY Towers bu programıyla çalışma, konaklama, gastronomi, sosyal yaşam ve kültürel etkinlik işlevlerini bir arada sunarak İFM'nin en çok yönlü yapısı olmayı hedeflemektedir.

\begin{figure}[t]
    \centering
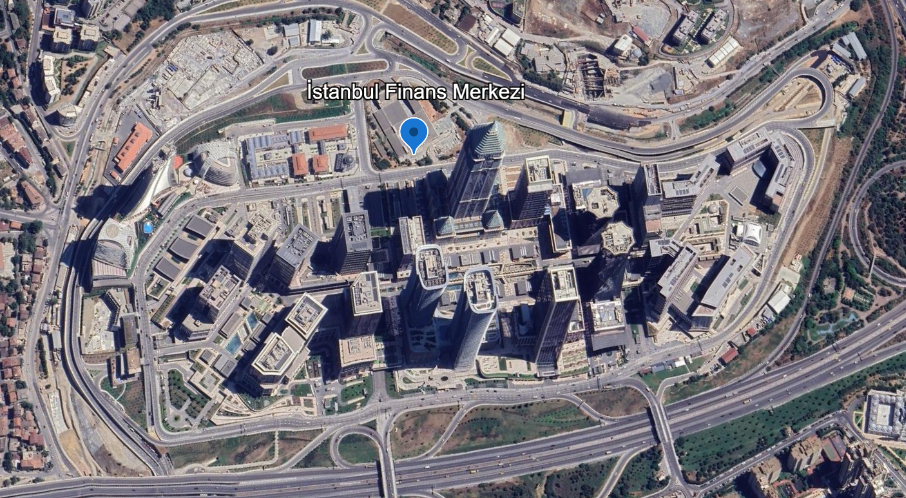
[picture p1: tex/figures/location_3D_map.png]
    
    \caption{İstanbul Finans Merkezi (İFM) yerleşkesi ve GÜRSOY Towers proje konumu.}
    \label{fig:ifm_location}
\end{figure}

\newpage

% --- 2. MİMARİ TASARIM ---
\section{MİMARİ TASARIM}
Binanın mimari tasarımında dikkate alınan tasarım kriterlerinin çevresel ve ekonomik koşulları da kapsayacak şekilde ilgili görsellerle desteklenerek açıklandığı bölümdür (şekiller hariç maksimum 1 A4 sayfa).

\newpage

% --- 3. YAPISAL SİSTEM TANIMI ve TASARIMI ---
\section{YAPISAL SİSTEM TANIMI ve TASARIMI}

\noindent\textit{Saha koşulları ve deprem tehlikesi.}
Proje sahası, İstanbul Finans Merkezi ($41.00^\circ$\,K, $29.11^\circ$\,D) mevkiinde olup Kuzey Anadolu Fayı'na yakın konumu itibarıyla birinci derece deprem kuşağında yer almaktadır.
AFAD~\cite{afad2024} DD-2 tehlike düzeyinde tasarım spektral ivmeleri $S_{DS}\!=\!1.008$\,g, $S_{D1}\!=\!0.514$\,g olarak belirlenmiştir~\cite{tbdy2018}.
Saha ZD zemin sınıfında olup kalın yumuşak zemin tabakası uzun periyotlu deprem dalgalarını kuvvetlendirerek üstyapıya aktarmaktadır; bu durum yapısal tasarımda hem yanal rijitliği hem de yeterli şekil değiştirme kapasitesini zorunlu kılmaktadır.

\noindent\textit{Taşıyıcı sistem tipi ve gerekçeleri.}
Salt moment çerçevesi sünek olmakla birlikte yanal ötelenmeyi yeterince sınırlayamamakta; çaprazlı sistem ise yüksek rijitlik sağlamakla beraber gevrek kırılmaya açık bulunmaktadır.
Bu dengeyi kurmak üzere \textit{çerçeve--çapraz hibrit} sistem tercih edilmiştir~\cite{nehrp2009}: çapraz elemanlar yatay yükleri doğrudan temele ileterek yanal ötelenmeyi kontrol altına almakta; moment çerçevesi ise enerji yutma ve plastik yeniden dağılım imk\^{a}nı sunmaktadır.
İkiz kule konfigürasyonu benimsenerek ${\sim}H/4$, $H/2$, $3H/4$ ve tepe kotlarına yerleştirilen dört köprü ile kuleler kuplajlanmış; global rijitlik artırılmış, diferansiyel ötelenme ve burulma talebi asgariye indirilmiştir~\cite{patoliya2023, tambunan2024}.
Köprüler aynı zamanda iki kulenin eş fazlı titreşimini sağlayarak antisimetrik modları bastırma işlevi de görmektedir.

\noindent\textit{İzlenen yaklaşımlar ve kabuller.}
Yapısal model \textsc{OpenSees}\textsuperscript{\textregistered}~\cite{opensees} ortamında oluşturulmuştur.
Kolon--kiriş birleşimleri rijit, çapraz uçları mafsallı kabul edilmiştir.
Güçlü kolon--zayıf kiriş ilkesi gözetilerek plastik mafsalların kiriş uçlarında oluşması hedeflenmiş, kat mekanizması ihtimali bertaraf edilmiştir~\cite{tbdy2018}.
Her iki doğrultuda tam simetri tesis edilerek kütle merkezi ile rijitlik merkezi çakıştırılmış ($e_x/L_x = 0$, $e_y/L_y = 0$); böylece deprem yüklerinin burulma bileşeni sıfırlanmıştır.
A1a burulma düzensizliği kontrolünde zemin katta $\eta_{bi} = 1{,}69 < 2{,}0$, üst katlarda $\eta_{bi} < 1{,}2$ elde edilmiştir~\cite{teblig2024}.
Deprem analizinde Mod Birleştirme Yöntemi (MBY) ile zaman tanım alanında hesap (ZTAH) uygulanmış; modal katkılar CQC kuralı ($\xi\!=\!0.05$) ile birleştirilmiştir~\cite{tbdy2018}.

\noindent\textit{Sistem geometrisi ve çapraz yerleşim stratejisi.}
Yapı $20\!\times\!20\,\mathrm{m}$ taban alanı üzerinde iki simetrik kuleden oluşmaktadır (Şekil~\ref{fig:sistem}).
Her kule $15\!\times\!8\,\mathrm{m}$ plan boyutunda, $7\!\times\!3$ düşey kolon ağı üzerine inşa edilmiş olup zemin kat yüksekliği $h_0\!=\!4{,}5\,\mathrm{m}$, sonraki 24~kat $h\!=\!3{,}0\,\mathrm{m}$; toplam yükseklik $H\!=\!76{,}5\,\mathrm{m}$'dir.
Kuleler arası açıklık $4{,}0\,\mathrm{m}$ olup köprüler 6., 12., 18.\ ve 25.~katlarda konumlandırılmıştır.
$X$ doğrultusunda köşe açıklıkları ($1{,}35\,\mathrm{m}$) kısa tutularak çerçeve rijitliği takviye edilmiş; $Y$ doğrultusunda simetrik iki açıklık ($3{,}85\,\mathrm{m}$) ile rijitlik dağılımı dengelenmiştir.
Çapraz elemanlar, deprem kesme kuvvetinin en yoğun olduğu alt katlara konsantre edilmiştir (Şekil~\ref{fig:sistem}).
$XZ$ düzleminde iç açıklıklarda zemin--13.~kat arasında X-çapraz çifti uygulanarak kesme kuvveti basınç ve çekme bileşenlerine ayrıştırılmıştır.
Dış açıklıklarda alt dört katta her katta tam çapraz, üst katlarda ise üçer katlık zikzak düzeninde çapraz yerleştirilmiştir; bu gradyan, üst katlardaki kesme kuvveti düşüşüne paralel olarak rijitlik dağılımını optimize etmektedir.
$YZ$ düzleminde ise köprü katlarındaki düğüm noktalarını güçlendirmek amacıyla \textit{mega brace (mega çapraz)} konfigürasyonu benimsenmiştir.
Zemin bloğunda (0--6.~kat) çaprazlar zemin kattan başlayarak iki kat yüksekliğinde orta kolonda birleşmekte (2.~kat seviyesi) ve oradan köprü altı düğümüne (6.~kat altı) açılmaktadır.
Üst bloklarda mega çaprazlar bir köprü altı düğümünden bir sonraki köprü altı düğümüne uzanmakta, merkez düğüm noktaları orta kolonda oluşmaktadır.
Köprü üstü düğüm noktaları ek çaprazlarla mega brace merkezine bağlanarak köprü seviyelerinde rijit düğüm noktaları tesis edilmiştir.
En üst katta (24--25.~kat) köprü üzerinden çatıya doğru kapatma çaprazları uygulanmıştır.

% --- Şekil: Yapısal sistem ---
\begin{figure}[H]
\centering
\resizebox{0.93\textwidth}{!}{%
\begin{tikzpicture}[font=\scriptsize]
\pgfmathsetmacro{\s}{0.055}
% ===== (a) ÖN GÖRÜNÜM (XZ düzlemi) =====
\begin{scope}[xscale=\s, yscale=\s]
% Zemin
\fill[black!6] (-4,-5) rectangle (33,0);
\draw[black!40] (-4,0) -- (33,0);
% --- Kolonlar (siyah) ---
\foreach \x in {0.3,3,11.3,15,18.7,27,29.7} {
  \draw[black, line width=0.4pt] (\x,0) -- (\x,153);
}
% --- Kirişler beam_x: her kat (koyu gri) ---
\draw[black!70, line width=0.2pt] (0.3,0) -- (29.7,0);
\draw[black!70, line width=0.2pt] (0.3,9) -- (29.7,9);
\foreach \f in {2,...,25} {
  \pgfmathsetmacro{\z}{9+(\f-1)*6}
  \draw[black!70, line width=0.2pt] (0.3,\z) -- (29.7,\z);
}
% --- Çapraz XZ: iç 3.7cm açıklıklar, X-cross kat 0--12 + son 2 kat (açık gri) ---
\foreach \za/\zb in {0/9,9/15,15/21,21/27,27/33,33/39,39/45,45/51,51/57,57/63,63/69,69/75,75/81,141/147,147/153} {
  \foreach \xa/\xb in {11.3/15,15/18.7} {
    \draw[black!40, line width=0.2pt] (\xa,\za)--(\xb,\zb);
    \draw[black!40, line width=0.2pt] (\xb,\za)--(\xa,\zb);
  }
}
% --- Çapraz XZ: 8cm açıklıklar (3-11, 19-27), ilk 4 kat tek, sonra 3'er katlık (açık gri) ---
\foreach \za/\zb in {0/9,9/15,15/21,21/27,27/45,45/63,63/81,81/99,99/117,117/135,135/153} {
  \foreach \xa/\xb in {3/11.3,18.7/27} {
    \draw[black!40, line width=0.2pt] (\xa,\za)--(\xb,\zb);
    \draw[black!40, line width=0.2pt] (\xb,\za)--(\xa,\zb);
  }
}
% --- Düğüm noktaları (beyaz dolu daire) ---
\foreach \x in {0.3,3,11.3,15,18.7,27,29.7} {
  % Zemin kat
  \fill[white] (\x,0) circle (0.8); \draw[black, line width=0.15pt] (\x,0) circle (0.8);
  % 1. kat (z=9)
  \fill[white] (\x,9) circle (0.8); \draw[black, line width=0.15pt] (\x,9) circle (0.8);
  % Üst katlar
  \foreach \f in {2,...,25} {
    \pgfmathsetmacro{\z}{9+(\f-1)*6}
    \fill[white] (\x,\z) circle (0.8); \draw[black, line width=0.15pt] (\x,\z) circle (0.8);
  }
}
% --- Ölçüler ---
\draw[<->,thin,black!60] (-3,0) -- node[left,font=\tiny,rotate=90,anchor=south]{$H\!=\!76.5$} (-3,153);
\draw[<->,thin,black!60] (0.3,-3.5) -- node[below,font=\tiny]{$15$} (29.7,-3.5);
\draw[<->,thin,black!40] (31.5,0) -- node[right,font=\tiny]{$4.5$} (31.5,9);
\draw[<->,thin,black!40] (31.5,9) -- node[right,font=\tiny]{$3.0$} (31.5,15);
% Alt başlık
\node[font=\tiny,anchor=north] at (15,-7) {(a) Ön görünüm ($XZ$)};
\end{scope}
% ===== (b) YAN GÖRÜNÜM (YZ düzlemi) =====
\begin{scope}[shift={(2.9,0)}, xscale=\s, yscale=\s]

% --- Arka Plan ve Zemin ---
\fill[black!6] (-4,-5) rectangle (43,0);
\draw[black!40] (-4,0) -- (43,0);

% ==========================================
% 1. KOLONLAR VE KİRİŞLER (Sabit Yapı)
% ==========================================

% --- Kolonlar Kule 1 (Sol) ---
\foreach \y in {0.3,8,15.7} { \draw[black, line width=0.4pt] (\y,0) -- (\y,153); }
% --- Kolonlar Kule 2 (Sağ) ---
\foreach \y in {24.3,32,39.7} { \draw[black, line width=0.4pt] (\y,0) -- (\y,153); }

% --- Kirişler (Kat Döşemeleri) ---
% Zemin ve 1. Kat
\foreach \towerL/\towerR in {0.3/15.7, 24.3/39.7} {
    \draw[black!70, line width=0.2pt] (\towerL,0)--(\towerR,0);
    \draw[black!70, line width=0.2pt] (\towerL,9)--(\towerR,9);
}
% Üst Katlar (2. kattan 25. kata kadar)
\foreach \f in {2,...,25} {
    \pgfmathsetmacro{\z}{9+(\f-1)*6}
    \draw[black!70, line width=0.2pt] (0.3,\z)--(15.7,\z);   % Kule 1
    \draw[black!70, line width=0.2pt] (24.3,\z)--(39.7,\z); % Kule 2
}

% ==========================================
% 2. YENİ ÇAPRAZ SİSTEMİ (Mega Brace)
% ==========================================

% --- (A) ZEMİN BLOĞU (0m -> 33m) ---
% Z=0 (Zemin) -> Z=15 (2. Kat, Orta) -> Z=33 (Köprü 1 Altı)
\foreach \midX/\leftX/\rightX in {8/0.3/15.7, 32/24.3/39.7} {
    % Alt Parça: Zeminden Ortaya (0 -> 15)
    \draw[black!50, line width=0.3pt] (\leftX,0) -- (\midX,15);
    \draw[black!50, line width=0.3pt] (\rightX,0) -- (\midX,15);
    % Üst Parça: Ortadan Köprü Altına (15 -> 33)
    \draw[black!50, line width=0.3pt] (\midX,15) -- (\leftX,33);
    \draw[black!50, line width=0.3pt] (\midX,15) -- (\rightX,33);
}

% --- (B) ARA BLOKLAR (Mega Brace: Köprü Altı -> Köprü Altı) ---
% 1. Modül: Köprü 1 Altı (33) -> Köprü 2 Altı (69). Merkez Z=51. Köprü 1 Üstü=39.
% 2. Modül: Köprü 2 Altı (69) -> Köprü 3 Altı (105). Merkez Z=87. Köprü 2 Üstü=75.
% 3. Modül: Köprü 3 Altı (105) -> Köprü 4 Altı (141). Merkez Z=123. Köprü 3 Üstü=111.

\foreach \zBot/\zTop/\zMid/\zBridgeTop in {33/69/51/39, 69/105/87/75, 105/141/123/111} {
    \foreach \midX/\leftX/\rightX in {8/0.3/15.7, 32/24.3/39.7} {
        % 1. Ana Elmas: Köprü Altından (zBot) Mega Merkeze (zMid)
        \draw[black!50, line width=0.3pt] (\leftX, \zBot) -- (\midX, \zMid);
        \draw[black!50, line width=0.3pt] (\rightX, \zBot) -- (\midX, \zMid);
        
        % 2. Ana Elmas: Mega Merkezden (zMid) Bir Sonraki Köprü Altına (zTop)
        \draw[black!50, line width=0.3pt] (\midX, \zMid) -- (\leftX, \zTop);
        \draw[black!50, line width=0.3pt] (\midX, \zMid) -- (\rightX, \zTop);
        
        % 3. Ek Bağlantı: Köprü Üstü -> Mega Brace Merkezi
        \draw[black!50, line width=0.3pt] (\leftX, \zBridgeTop) -- (\midX, \zMid);
        \draw[black!50, line width=0.3pt] (\rightX, \zBridgeTop) -- (\midX, \zMid);
    }
}

% --- (C) EN ÜST KAT (141m -> 153m) ---
\foreach \midX/\leftX/\rightX in {8/0.3/15.7, 32/24.3/39.7} {
    \draw[black!50, line width=0.3pt] (\leftX, 141) -- (\midX, 153);
    \draw[black!50, line width=0.3pt] (\rightX, 141) -- (\midX, 153);
}

% ==========================================
% 3. KÖPRÜLER (Yatay Bağlantılar)
% ==========================================
\foreach \za/\zb in {33/39, 69/75, 105/111} {
    % Kolon
    \draw[black!80, line width=0.4pt] (20,\za)--(20,\zb);
    % Kirişler
    \draw[black!70, line width=0.3pt] (15.7,\za)--(24.3,\za);
    \draw[black!70, line width=0.3pt] (15.7,\zb)--(24.3,\zb);
    % Çapraz kafes
    \draw[black!35, line width=0.2pt] (15.7,\za)--(20,\zb);
    \draw[black!35, line width=0.2pt] (20,\za)--(15.7,\zb);
    \draw[black!35, line width=0.2pt] (20,\za)--(24.3,\zb);
    \draw[black!35, line width=0.2pt] (24.3,\za)--(20,\zb);
}

% --- En Üst Köprü (Çift katmanlı) ---
\draw[black!80, line width=0.4pt] (20,141)--(20,153);
\draw[black!70, line width=0.3pt] (15.7,141)--(24.3,141);
\draw[black!70, line width=0.3pt] (15.7,147)--(24.3,147);
\draw[black!70, line width=0.3pt] (15.7,153)--(24.3,153);
% Kafes
\draw[black!35, line width=0.2pt] (15.7,141)--(20,147);
\draw[black!35, line width=0.2pt] (20,141)--(15.7,147);
\draw[black!35, line width=0.2pt] (20,141)--(24.3,147);
\draw[black!35, line width=0.2pt] (24.3,141)--(20,147);
\draw[black!35, line width=0.2pt] (15.7,147)--(20,153);
\draw[black!35, line width=0.2pt] (20,147)--(15.7,153);
\draw[black!35, line width=0.2pt] (20,147)--(24.3,153);
\draw[black!35, line width=0.2pt] (24.3,147)--(20,153);

% ==========================================
% 4. DÜĞÜM NOKTALARI
% ==========================================
\foreach \y in {0.3,8,15.7, 24.3,32,39.7} {
    % Zemin
    \fill[white] (\y,0) circle (0.8); \draw[black, line width=0.15pt] (\y,0) circle (0.8);
    % 1. Kat
    \fill[white] (\y,9) circle (0.8); \draw[black, line width=0.15pt] (\y,9) circle (0.8);
    % Diğer Katlar
    \foreach \f in {2,...,25} {
        \pgfmathsetmacro{\z}{9+(\f-1)*6}
        \fill[white] (\y,\z) circle (0.8); \draw[black, line width=0.15pt] (\y,\z) circle (0.8);
    }
}
% Köprü Düğüm Noktaları (Orta)
\foreach \za in {33,39,69,75,105,111,141,147,153} {
    \fill[white] (20,\za) circle (0.8); \draw[black, line width=0.15pt] (20,\za) circle (0.8);
}

% ==========================================
% 5. ETİKETLER VE ÖLÇÜLER
% ==========================================
\node[font=\tiny,black!50] at (8,156) {Kule\,1};
\node[font=\tiny,black!50] at (32,156) {Kule\,2};

\node[font=\tiny,black!60,anchor=west] at (40.8,36) {K.6};
\node[font=\tiny,black!60,anchor=west] at (40.8,72) {K.12};
\node[font=\tiny,black!60,anchor=west] at (40.8,108) {K.18};
\node[font=\tiny,black!60,anchor=west] at (40.8,147) {K.25};

\draw[<->,thin,black!60] (0.3,-3.5) -- node[below,font=\tiny]{$8$} (15.7,-3.5);
\draw[<->,thin,black!60] (15.7,-3.5) -- node[below,font=\tiny]{$4$} (24.3,-3.5);
\draw[<->,thin,black!60] (24.3,-3.5) -- node[below,font=\tiny]{$8$} (39.7,-3.5);
\draw[<->,thin,black!60] (-3,0) -- node[left,font=\tiny,rotate=90,anchor=south]{$76.5$} (-3,153);

\node[font=\tiny,anchor=north] at (20,-7) {(b) Yan görünüm ($YZ$) -- Mega Brace Sistemi};

\end{scope}
\end{tikzpicture}%
}
\caption{V10 modelinin yapısal sistemi: (a)~ön görünüm ($XZ$)---iç açıklıklarda X-çapraz (0--12.~kat), dış açıklıklarda 3~katlık zikzak; (b)~yan görünüm ($YZ$)---mega brace çapraz sistemi ve köprü kafes bağlantıları. Siyah: kolon, koyu gri: kiriş/köprü, açık gri: çapraz. Beyaz daireler: düğüm noktaları. Ölçüler metre cinsindendir.}
\label{fig:sistem}
\end{figure}

\newpage

% --- 4. ÇİZİMLER ---
\section{ÇİZİMLER}
Binanın her bir farklı katına ait plan ve iki ana doğrultudaki kesit çizimleri verilecektir.
\begin{itemize}
    \item Çizimler ayrıca "dwg" formatında ek olarak sunulacaktır.
\end{itemize}

\newpage

% ################### SORULAR VE CEVAPLAR ###################

% ==============================================================================
% SORU 1
% ==============================================================================
\section{SORULAR}
\subsection{Soru \RN{1}}

\textbf{Soru:} Yapı taşıyıcı sistemini belirlerken nelere dikkat ettiğinizi depreme dayanıklı bina tasarım ilkeleri çerçevesinde (taşıyıcı elemanların geometrisi ve yerleşimi, yeterli dayanım, rijitlik ve sünekliğin sağlanması gibi) açıklayınız.

\textbf{Cevap:} Taşıyıcı sistem seçiminde beş temel ilkeye dikkat edilmiştir: (1)~simetri ve düzenlilik, (2)~yeterli rijitlik, (3)~sürekli yük aktarımı, (4)~süneklik, (5)~hafiflik. TBDY 2018 ve uluslararası tasarım esasları çerçevesinde bu ilkeler aşağıda açıklanmıştır~\cite{tbdy2018, nehrp2009}.

\subsubsection{İkiz Kule ve Köprü Sistemi \& Simetri ve Düzenlilik}

Yüksek katlı yapı konfigürasyonu olarak iki ayrı kule ve bunları birbirine bağlayan köprü elemanlarından oluşan bir sistem tasarlanmıştır. Her kule 26 kattan oluşmakta olup $7 \times 3$ kolon gridi üzerine inşa edilmiştir. Literatürdeki çalışmalar, köprü bağlantılarının yapı yüksekliğinin $1/4$, $1/2$ ve $3/4$ seviyelerine yerleştirilmesinin sismik performansı optimize ettiğini göstermektedir~\cite{patoliya2023}. Bu doğrultuda köprüler yaklaşık olarak 6., 12., 18. ve 25. katlara konumlandırılmıştır. Bu konfigürasyon, yatay yükler altında kulelerin birlikte çalışmasını sağlamakta ve tek bir yüksek kuleye kıyasla daha dengeli yük dağılımı sunmaktadır. Yapının planda ve düşeyde düzenli olması, burulma düzensizliğini önlemek açısından temel gerekliliktir. İkiz kule sistemi her iki ana eksende ($X$, $Y$) simetrik olarak tasarlanmış; kütle merkezi ile rijitlik merkezi arasındaki eksantrisite en aza indirilmiştir. A1a burulma düzensizliği katsayısı zemin katta $\eta_{bi} = 1.69$ olup $2{,}0$'nin altındadır; üst katlarda $\eta_{bi} < 1.2$ değerleri elde edilmiştir~\cite{teblig2024}.

\subsubsection{Yeterli Yanal Rijitlik \& Sürekli Yük Aktarımı ve Süneklik}

Deprem yüklerinin güvenle temele aktarılması için yapının yatay kuvvetlere karşı yeterli rijitliğe sahip olması gerekmektedir. Çerçeve-çapraz hibrit sistem tercih edilerek, moment taşıyan çerçevelerin sünekliği ile çapraz elemanların rijitliği bir arada kullanılmıştır. Çapraz elemanlar $XZ$ ve $YZ$ düzlemlerinde stratejik noktalara yerleştirilmiş; köprü bağlantısı ise iki kule arasında yük paylaşımını sağlayarak global sistem rijitliğini artırmıştır. Deprem yüklerinin kesintisiz olarak temele iletilmesi için düşey taşıyıcı elemanlar tüm katlarda aynı konumda devam etmektedir. Kolon-kiriş düğüm noktaları rijit bağlantılı, çapraz elemanlar mafsallı modellenmiştir. Güçlü kolon--zayıf kiriş tasarım prensibi uygulanarak plastik mafsalların kiriş uçlarında oluşması hedeflenmiştir. CQC yöntemiyle hesaplanan göreli kat ötelemesi $\delta/h = 0.00117 < 0.008$'dir~\cite{tbdy2018}.

\subsubsection{Hafiflik ve Malzeme}

Deprem kuvvetleri yapı kütlesi ile doğru orantılı olduğundan, taşıyıcı sistemin mümkün olduğunca hafif tutulması esastır. Balsa ahşap malzeme ($E = 3.5$~GPa) kullanılarak yapısal analizler \textsc{OpenSees}\textsuperscript{\textregistered} yazılımı ile gerçekleştirilmiş~\cite{opensees}, ağırlık minimizasyonu ve rijitlik maksimizasyonu hedefleriyle iteratif optimizasyon yapılmıştır. \href{https://github.com/adzetto/DASK_26__DESIGN_AND_ANALYSIS}{\textcolor{blue}{Github deposunda}} tüm analiz ve optimizasyon kodları mevcuttur~\cite{github_repo}.
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

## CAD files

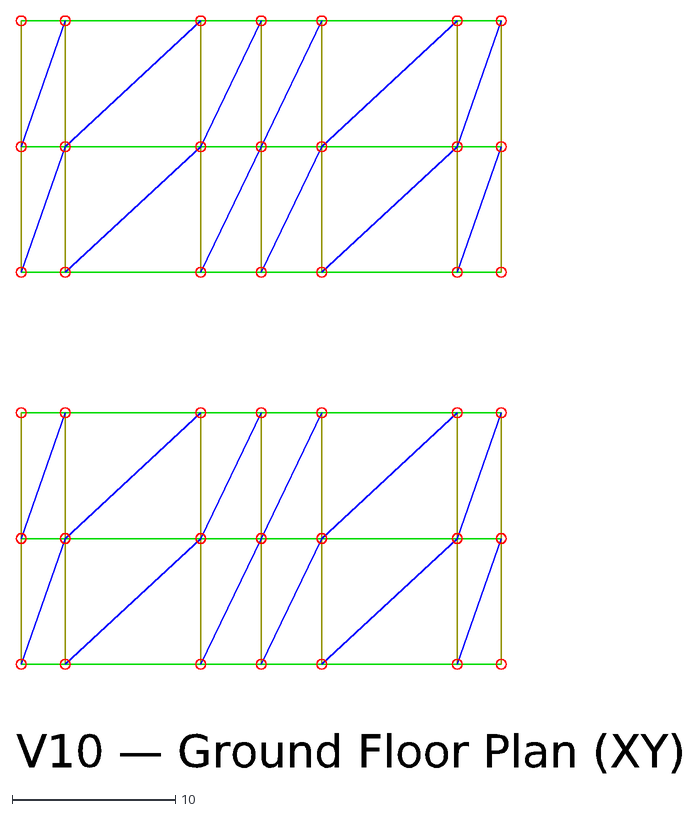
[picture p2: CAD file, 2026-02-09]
exports/twin_towers_v10_plan.dxf
V10 — Ground Floor Plan (XY)

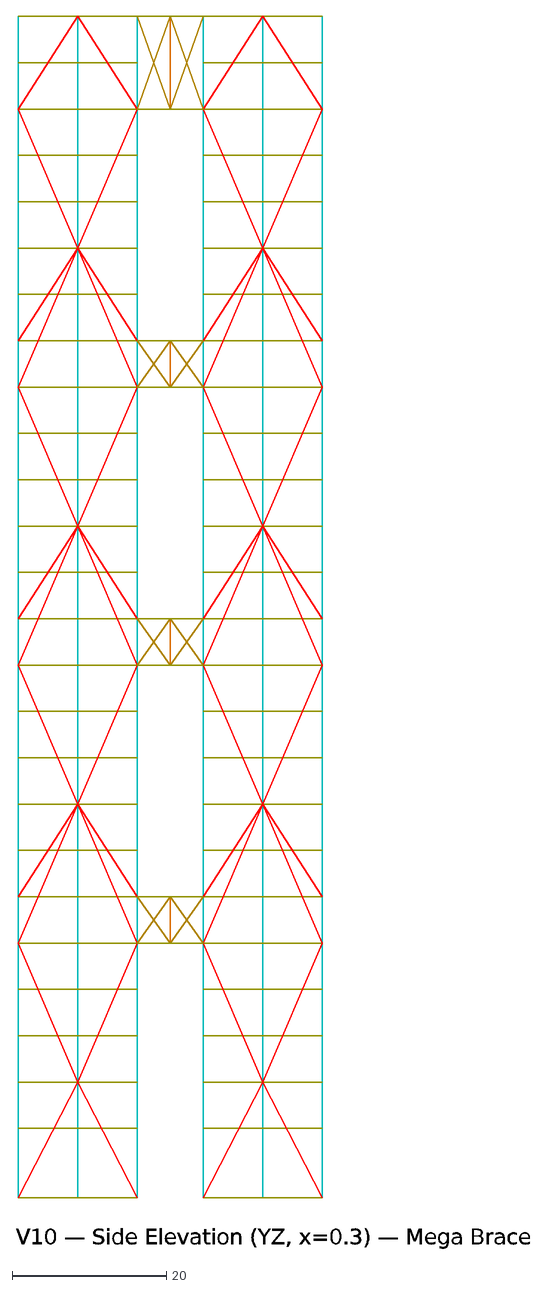
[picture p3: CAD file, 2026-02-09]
exports/twin_towers_v10_side.dxf
V10 — Side Elevation (YZ, x=0.3) — Mega Brace

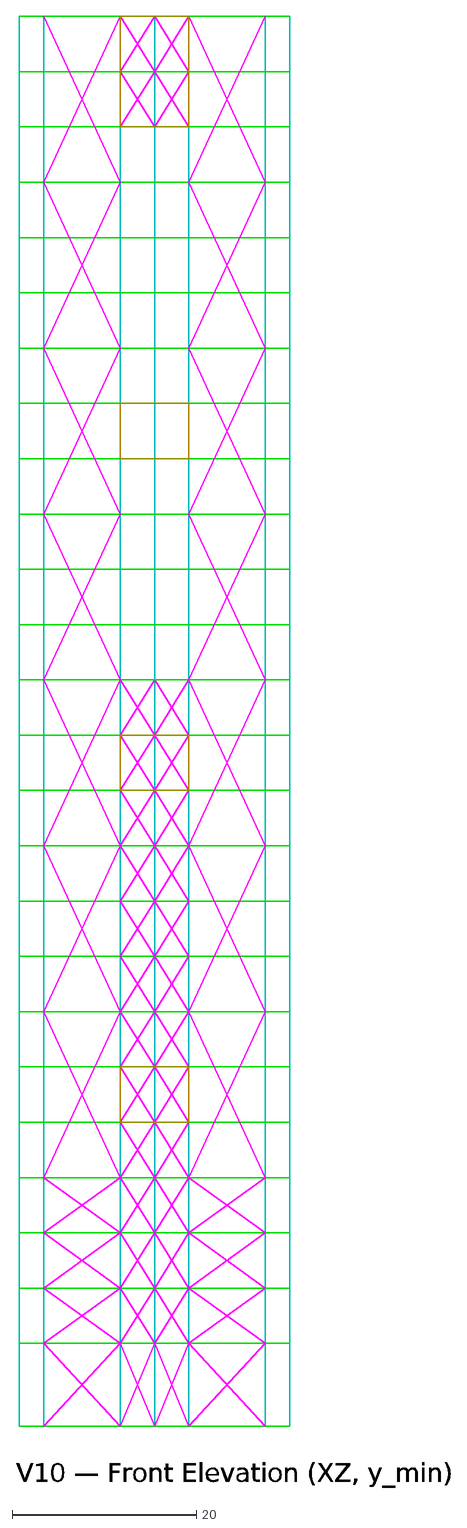
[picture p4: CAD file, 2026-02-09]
exports/twin_towers_v10_front.dxf
V10 — Front Elevation (XZ, y_min)

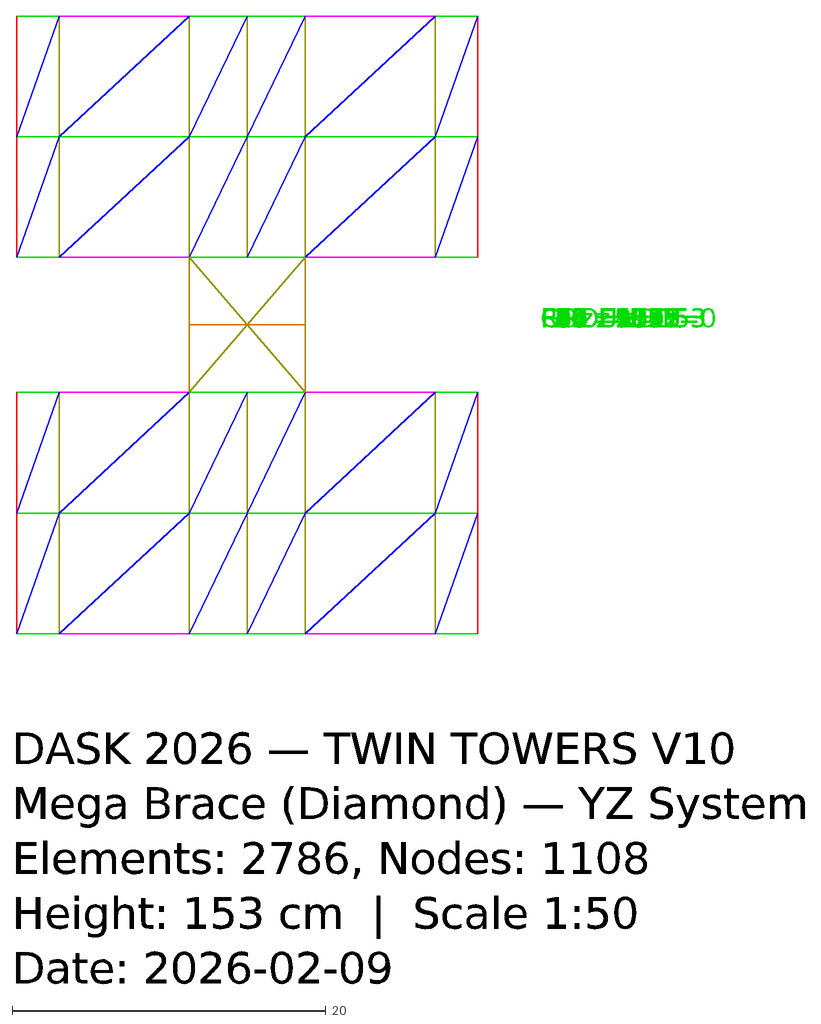
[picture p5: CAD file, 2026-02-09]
exports/twin_towers_v10_autocad.dxf
GROUND z=0
F1 z=9
F2 z=15
F3 z=21
F4 z=27
F5 z=33
F6 z=39
F7 z=45
F8 z=51
F9 z=57
F10 z=63
F11 z=69
F12 z=75
F13 z=81
F14 z=87
F15 z=93
F16 z=99
F17 z=105
F18 z=111
F19 z=117
F20 z=123
F21 z=129
F22 z=135
F23 z=141
F24 z=147
ROOF z=153
DASK 2026 — TWIN TOWERS V10
Mega Brace (Diamond) — YZ System
Elements: 2786, Nodes: 1108
Height: 153 cm | Scale 1:50
Date: 2026-02-09

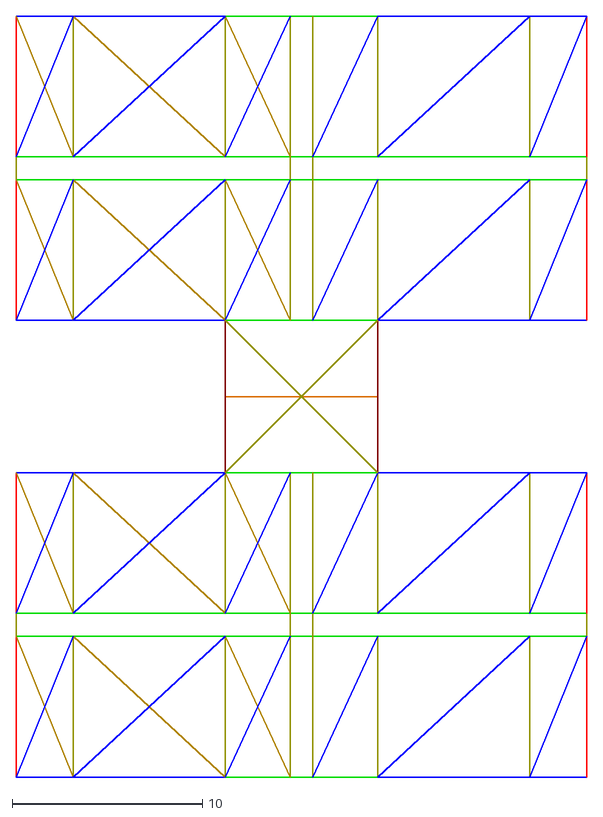
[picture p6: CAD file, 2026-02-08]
exports/twin_towers_v11.dxf
30.0 x 40.0

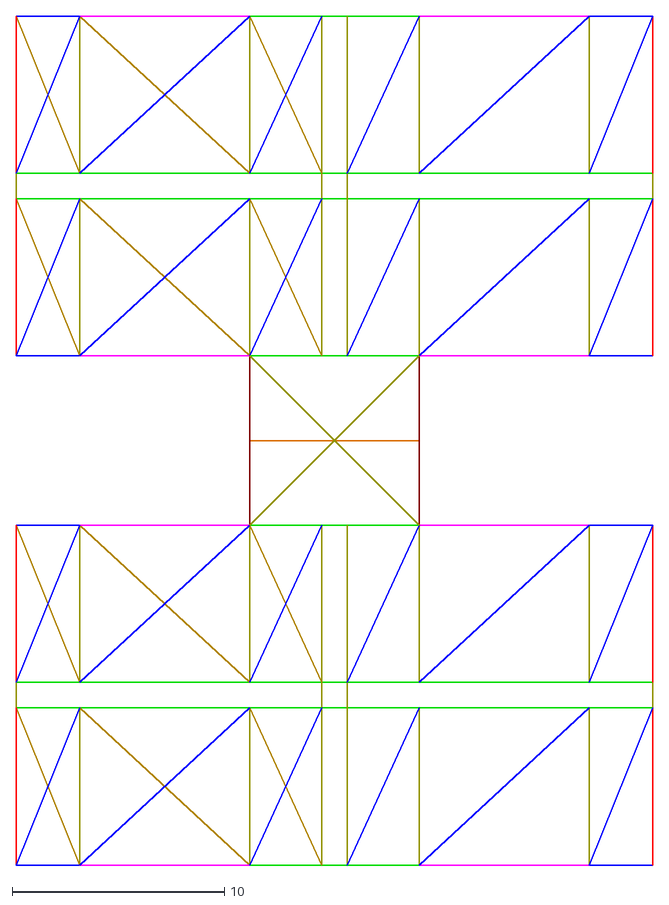
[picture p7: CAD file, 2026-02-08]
exports/twin_towers_v11b.dxf
30.0 x 40.0

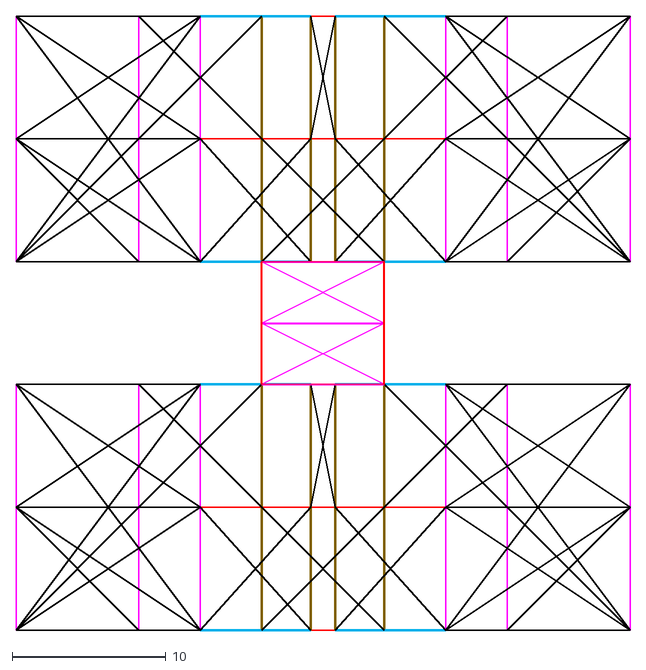
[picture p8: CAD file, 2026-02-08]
exports/twin_towers_dama_v2.dxf
40.0 x 40.0

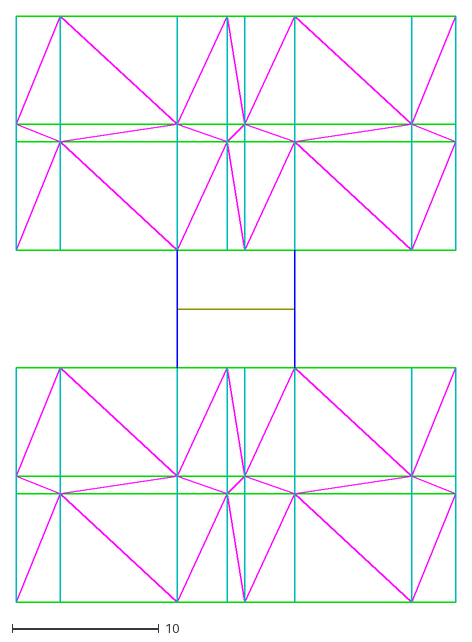
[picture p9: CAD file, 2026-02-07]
exports/twin_towers_v7_panels.dxf
30.0 x 40.0

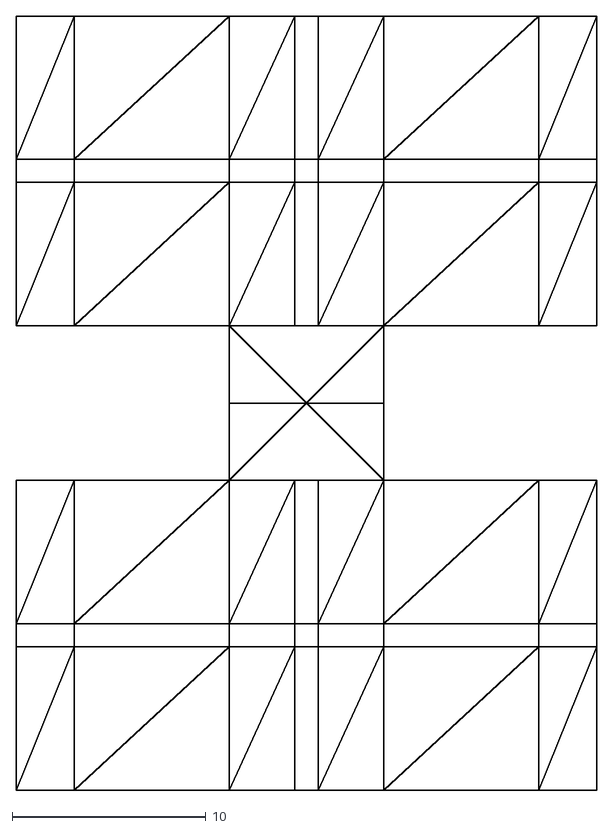
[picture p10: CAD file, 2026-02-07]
exports/twin_towers_v8_weights.dxf
30.0 x 40.0

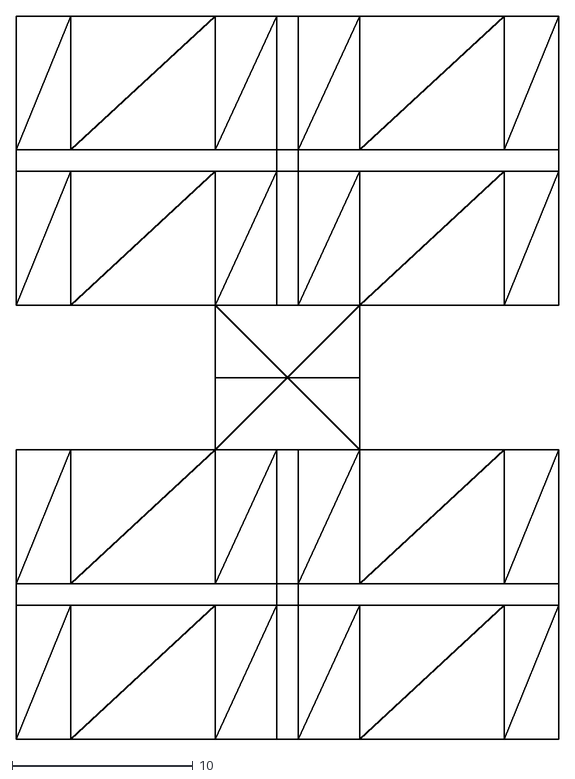
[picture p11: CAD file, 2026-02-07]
exports/twin_towers_v9_stiffened.dxf
30.0 x 40.0

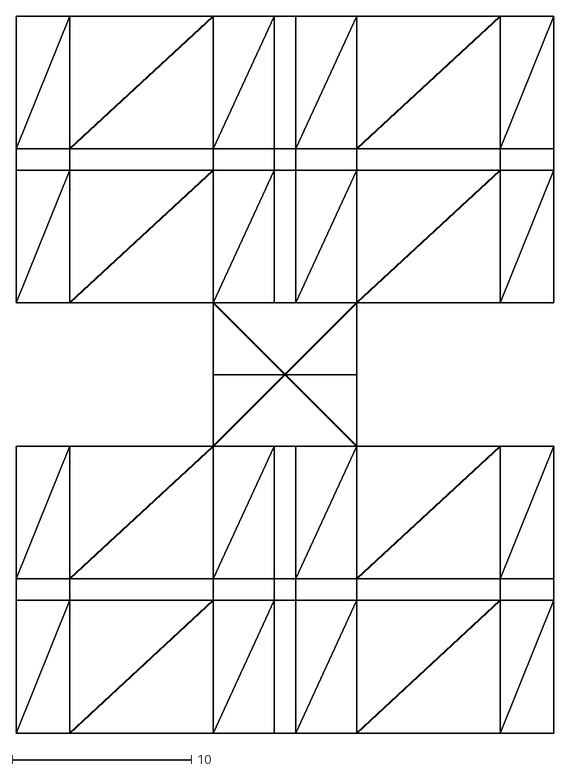
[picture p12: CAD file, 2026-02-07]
exports/twin_towers_v9b_stiffened.dxf
30.0 x 40.0

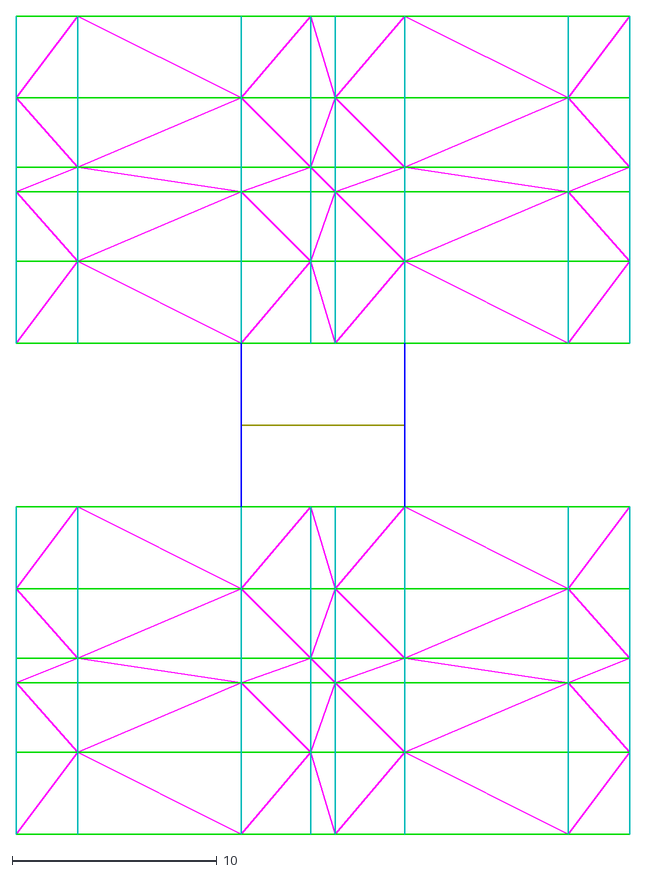
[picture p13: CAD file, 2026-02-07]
exports/twin_towers_v6_light.dxf
30.0 x 40.0

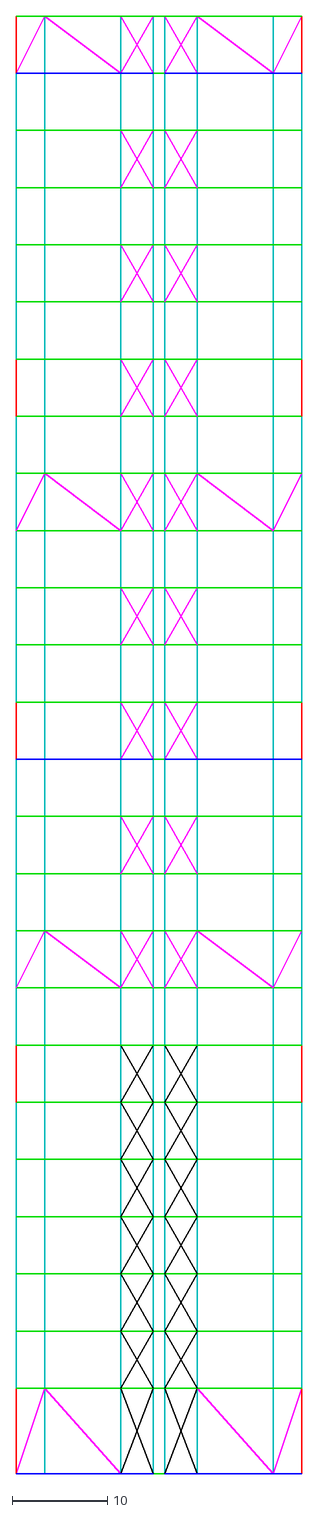
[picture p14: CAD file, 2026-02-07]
exports/twin_towers_v9_elevation.dxf
30.0 x 153.0

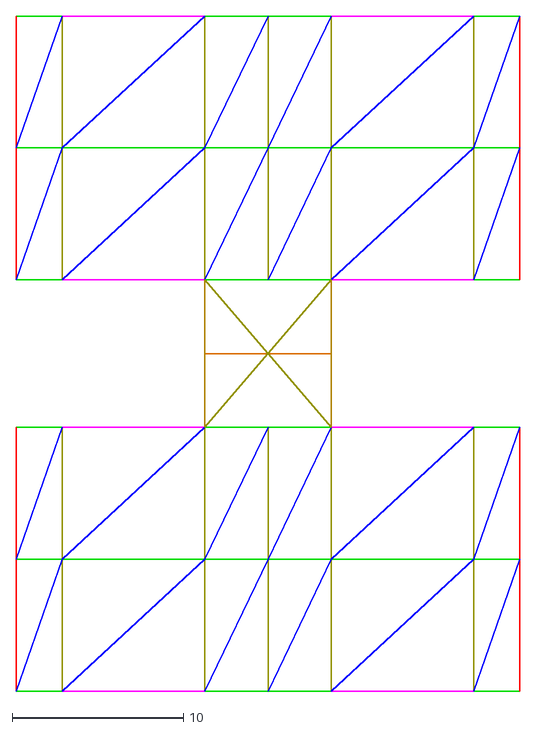
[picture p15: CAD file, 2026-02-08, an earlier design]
exports/twin_towers_v10.dxf
29.4 x 39.4

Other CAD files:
drawings/21.01.dwg
drawings/21.01_V2.dwg
exports/twin_towers_all_views.dxf
exports/twin_towers_v9_plan.dxf
TOWER.skp
exports/twin_towers_v9_autocad.dxf
results/twin_towers_v10.blend
results/twin_towers_v10_a4.blend

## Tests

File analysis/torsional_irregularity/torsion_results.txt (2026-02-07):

TBDY 2018 A1a Torsional Irregularity Analysis Results
======================================================
Generated: TBDY 2018 Torsion Analysis

Fundamental Period T1 = 0.19990821377601217 s
Base Shear Vt = 13.007596072882562 kN

Maximum eta_bi = 1.914992240926045
Critical Floor = 1
Critical Case = Y, -5%
D_bi = 2.5466633908381637

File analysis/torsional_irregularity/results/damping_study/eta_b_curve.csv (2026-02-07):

xi_pct | xi | eta_b
0.5 | 0.0050 | 1.3484
1.0 | 0.0100 | 1.2910
1.5 | 0.0150 | 1.2403
2.0 | 0.0200 | 1.1952
2.5 | 0.0250 | 1.1547
3.0 | 0.0300 | 1.1180
3.5 | 0.0350 | 1.0847
4.0 | 0.0400 | 1.0541
4.5 | 0.0450 | 1.0260
5.0 | 0.0500 | 1.0000
6.0 | 0.0600 | 0.9535
7.0 | 0.0700 | 0.9129
8.0 | 0.0800 | 0.8771
9.0 | 0.0900 | 0.8452
10.0 | 0.1000 | 0.8165
12.0 | 0.1200 | 0.7670
15.0 | 0.1500 | 0.7071
20.0 | 0.2000 | 0.6325

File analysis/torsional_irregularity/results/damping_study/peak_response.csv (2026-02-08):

xi | a0 | a1 | maxUx_T1_cm | maxUx_T2_cm | maxUy_T1_cm | maxUy_T2_cm | failed_steps
0.0050 | 0.244458 | 0.0000707031 | 1.12666691 | 1.12655663 | 0.00285562 | 0.00285273 | 0
0.0100 | 0.488917 | 0.0001414061 | 0.81335703 | 0.81328326 | 0.00225221 | 0.00225760 | 0
0.0200 | 0.977833 | 0.0002828123 | 0.61614829 | 0.61609935 | 0.00184810 | 0.00185174 | 0
0.0300 | 1.466750 | 0.0004242184 | 0.51705313 | 0.51701389 | 0.00157831 | 0.00158071 | 0
0.0500 | 2.444583 | 0.0007070307 | 0.44944125 | 0.44941705 | 0.00121895 | 0.00121979 | 0
0.0700 | 3.422416 | 0.0009898429 | 0.42365150 | 0.42362943 | 0.00098450 | 0.00098405 | 0
0.1000 | 4.889166 | 0.0014140614 | 0.39262060 | 0.39260094 | 0.00076463 | 0.00076265 | 0
0.1500 | 7.333749 | 0.0021210920 | 0.35174248 | 0.35172552 | 0.00056134 | 0.00055640 | 0
0.2000 | 9.778331 | 0.0028281227 | 0.31856577 | 0.31855065 | 0.00046199 | 0.00045710 | 0

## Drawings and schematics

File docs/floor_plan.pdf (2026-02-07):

## DASK 2026 Twin Towers

## Floor Plan & Structural Layout

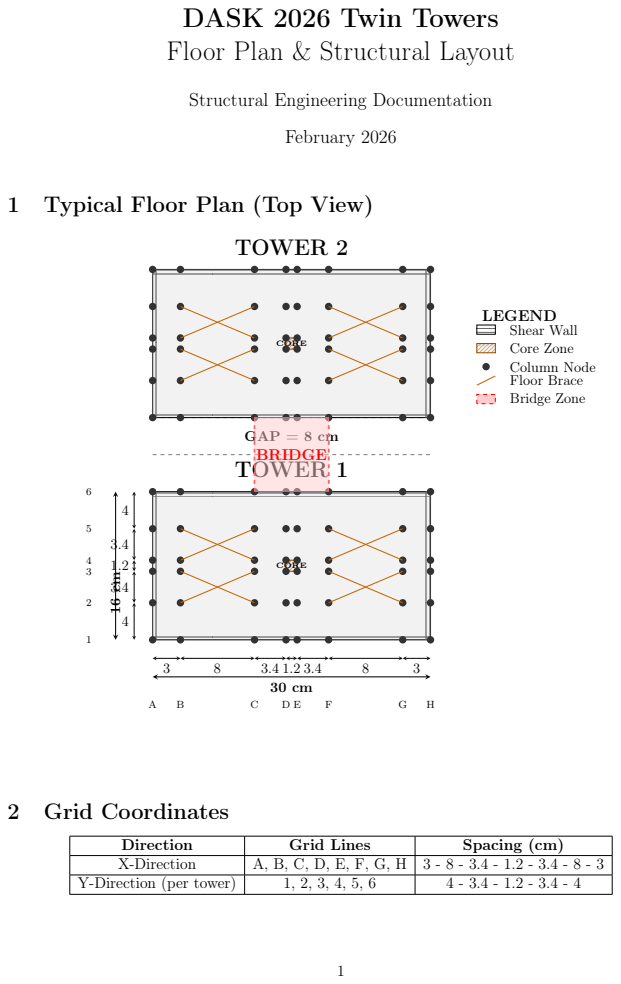
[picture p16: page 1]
February 2026; CORE; TOWER; GAP = 8 cm; TOWER 2; BRIDGE; LEGEND Shear Wall Core Zone Column Node Floor Brace Bridge Zone; 2 Grid Coordinates

Structural Engineering Documentation

1 Typical Floor Plan (Top View)

Direction | Grid Lines | Spacing (cm)
X-Direction | A, B, C, D, E, F, G, H | 3 - 8 - 3.4 - 1.2 - 3.4 - 8 - 3
Y-Direction (per tower) | 1, 2, 3, 4, 5, 6 | 4 - 3.4 - 1.2 - 3.4 - 4

## 3 Structural Summary

- Tower Dimensions: 30 × 16 cm each
- Gap Between Towers: 8 cm
- Total Footprint: 30 × 40 cm
- Core Zone: 1.2 × 1.2 cm at center
- Building Height: 159 m (27 floors)
- Fundamental Period: T1 = 0.0608 s
- Weight: 3.357 kg

## 4 Elevation Views

### 4.1 Front Elevation (Y = 0)

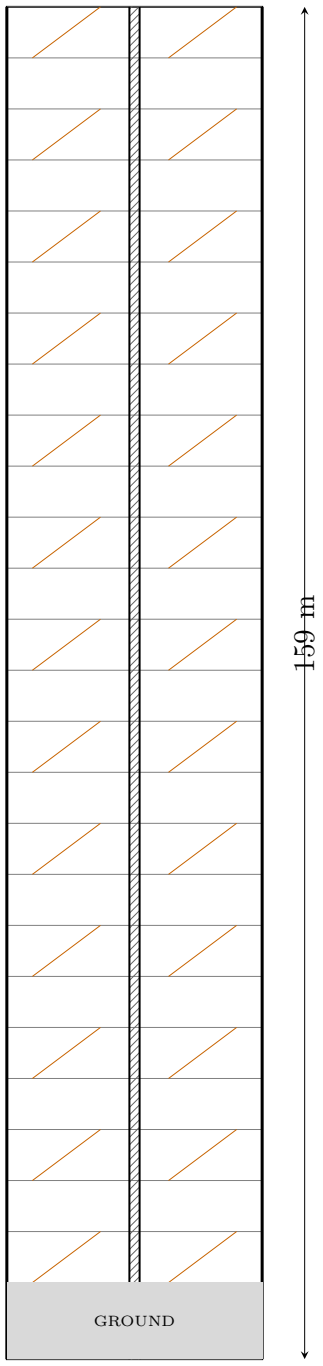
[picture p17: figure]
GROUND

30 cm
FRONT ELEVATION

### 4.2 Side Elevation (X = 0)

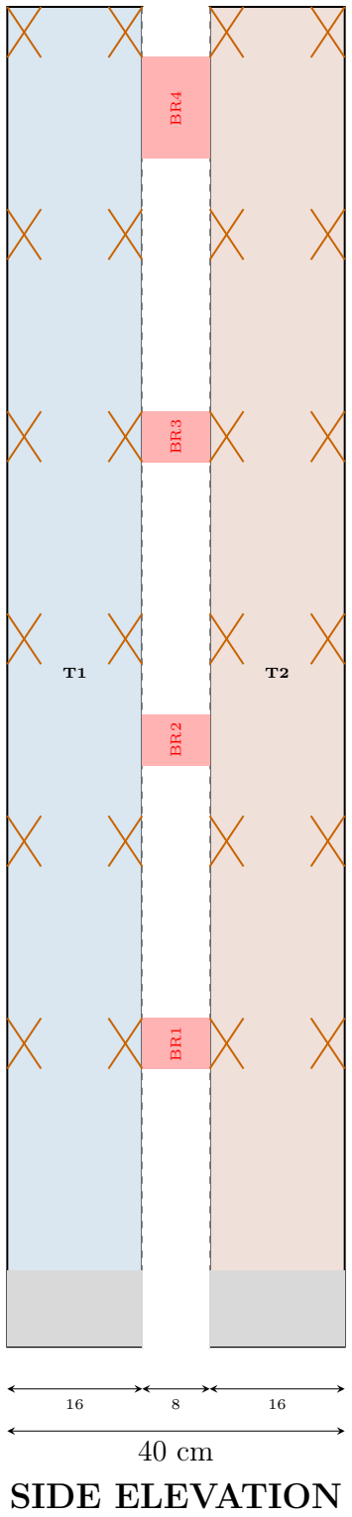
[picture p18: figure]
SIDE ELEVATION

## 5 TBDY2018 Design Spectrum

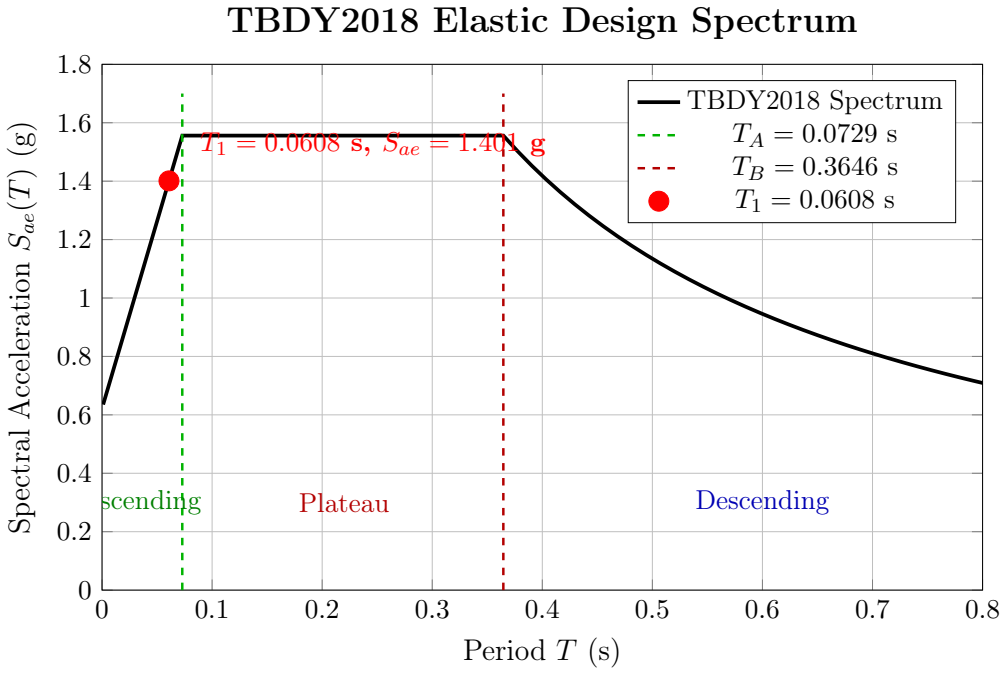
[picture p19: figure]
Ascending; Plateau; Descending; Period T (s); Spectral Acceleration; Sae(T) (g); TBDY2018 Elastic Design Spectrum; TBDY2018 Spectrum

T1 = 0.0608 s, Sae = 1.401 g | | TA TB | = 0.0729 s = 0.3646 s

### 5.1 Spectrum Parameters

Parameter | Value | Description
TA TB SDS | 0.0729 s 0.3646 s 1.556 g | Ascending → Plateau transition Plateau → Descending transition Short period design spectral acceleration
T1 Sae(T1) | 0.0608 s 1.401 g | Fundamental period of structure Spectral acceleration at T1

### 5.2 Design Region

Current Status: The structure is in the ASCENDING region (T1 < TA).

- This is the optimal region for seismic design.
- Lower spectral acceleration compared to plateau region.
- Margin to TA: 0.0729 − 0.0608 = 0.0121 s (16.6%)

Warning: Structures in the plateau region (TA ≤ T ≤ TB) experience maximum spectral acceleration, which can lead to critical design issues during earthquakes.

## 6 Modal Analysis Results

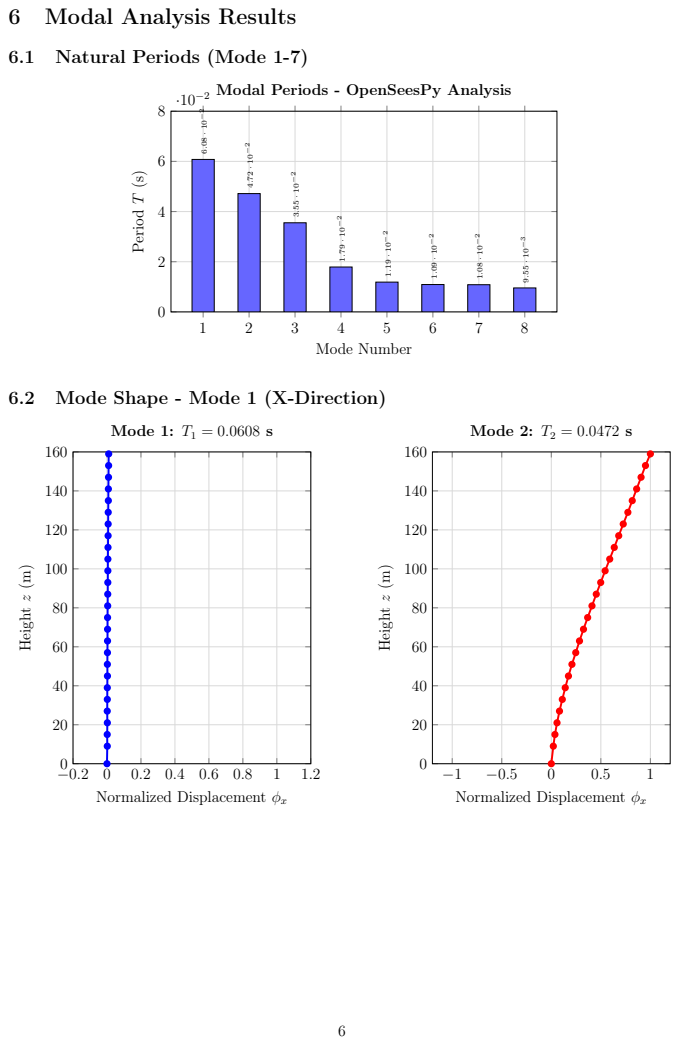
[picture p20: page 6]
Mode Number; Period; Modal Periods - OpenSeesPy Analysis; Height; Mode 1: T1 = 0.0608 s; Mode 2: T2 = 0.0472 s

6.1 Natural Periods (Mode 1-7)

6.2 Mode Shape - Mode 1 (X-Direction)

Normalized Displacement ϕx

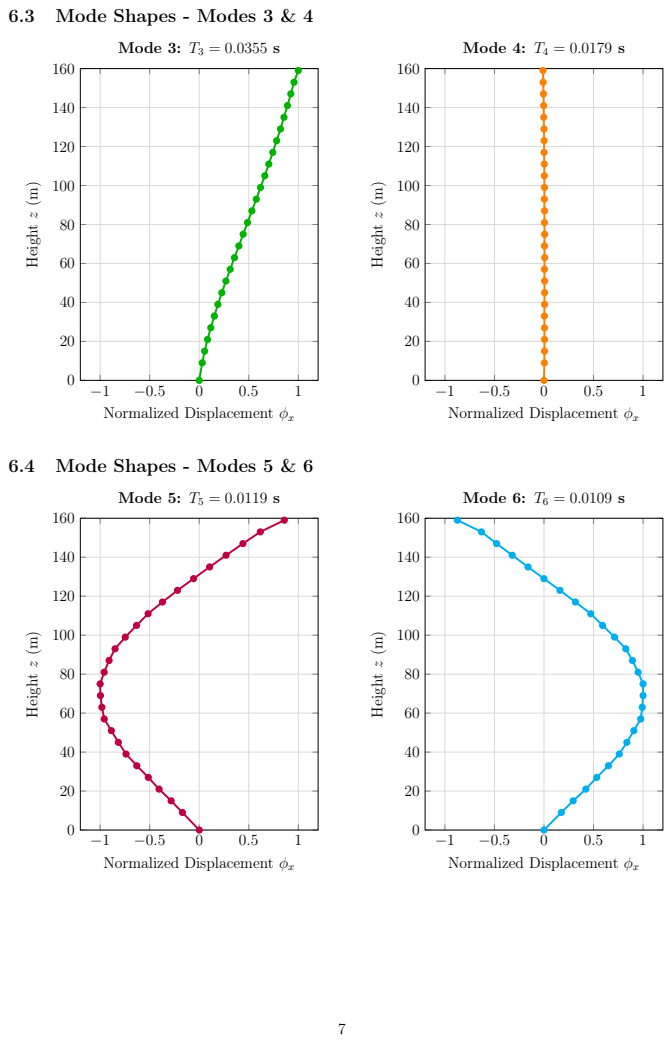
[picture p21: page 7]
Height; Mode 3: T3 = 0.0355 s; Mode 4: T4 = 0.0179 s; Mode 5: T5 = 0.0119 s; Mode 6: T6 = 0.0109 s

6.3 Mode Shapes - Modes 3 & 4

Normalized Displacement ϕx

6.4 Mode Shapes - Modes 5 & 6

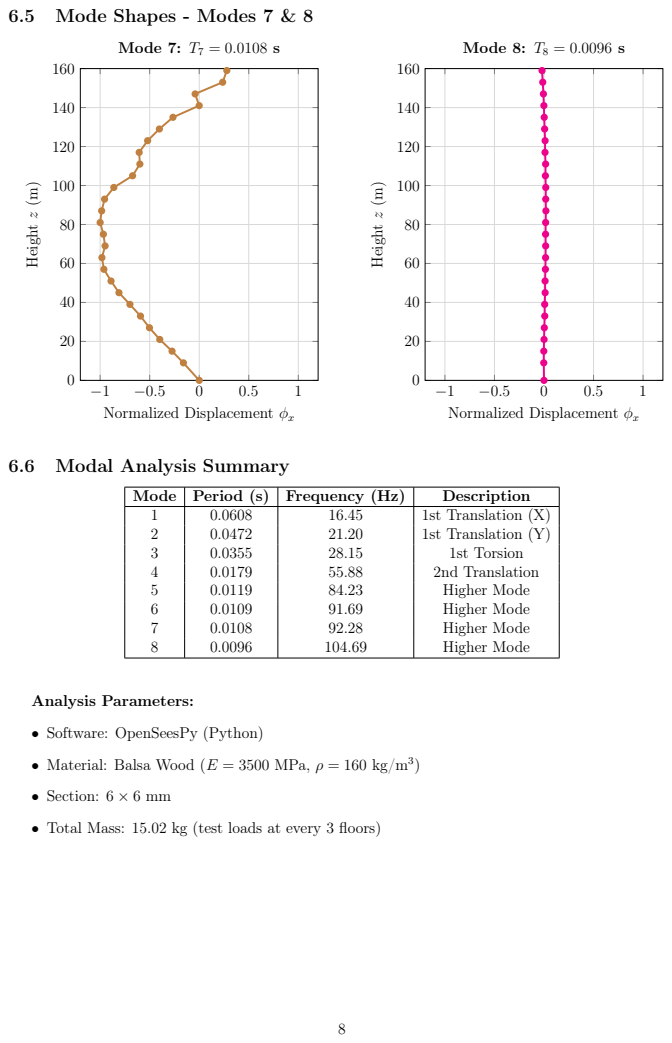
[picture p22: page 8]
Height; Mode 7: T7 = 0.0108 s; Mode 8: T8 = 0.0096 s; Analysis Parameters:; • Section: 6 × 6 mm

6.5 Mode Shapes - Modes 7 & 8

Normalized Displacement ϕx

6.6 Modal Analysis Summary

Mode | Period (s) | Frequency (Hz) | Description
1 2 3 4 5 6 7 8 | 0.0608 0.0472 0.0355 0.0179 0.0119 0.0109 0.0108 0.0096 | 16.45 21.20 28.15 55.88 84.23 91.69 92.28 104.69 | 1st Translation (X) 1st Translation (Y) 1st Torsion 2nd Translation Higher Mode Higher Mode Higher Mode Higher Mode

• Software: OpenSeesPy (Python)

• Material: Balsa Wood (E = 3500 MPa, ρ = 160 kg/m³

• Total Mass: 15.02 kg (test loads at every 3 floors)

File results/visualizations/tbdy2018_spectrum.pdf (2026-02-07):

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

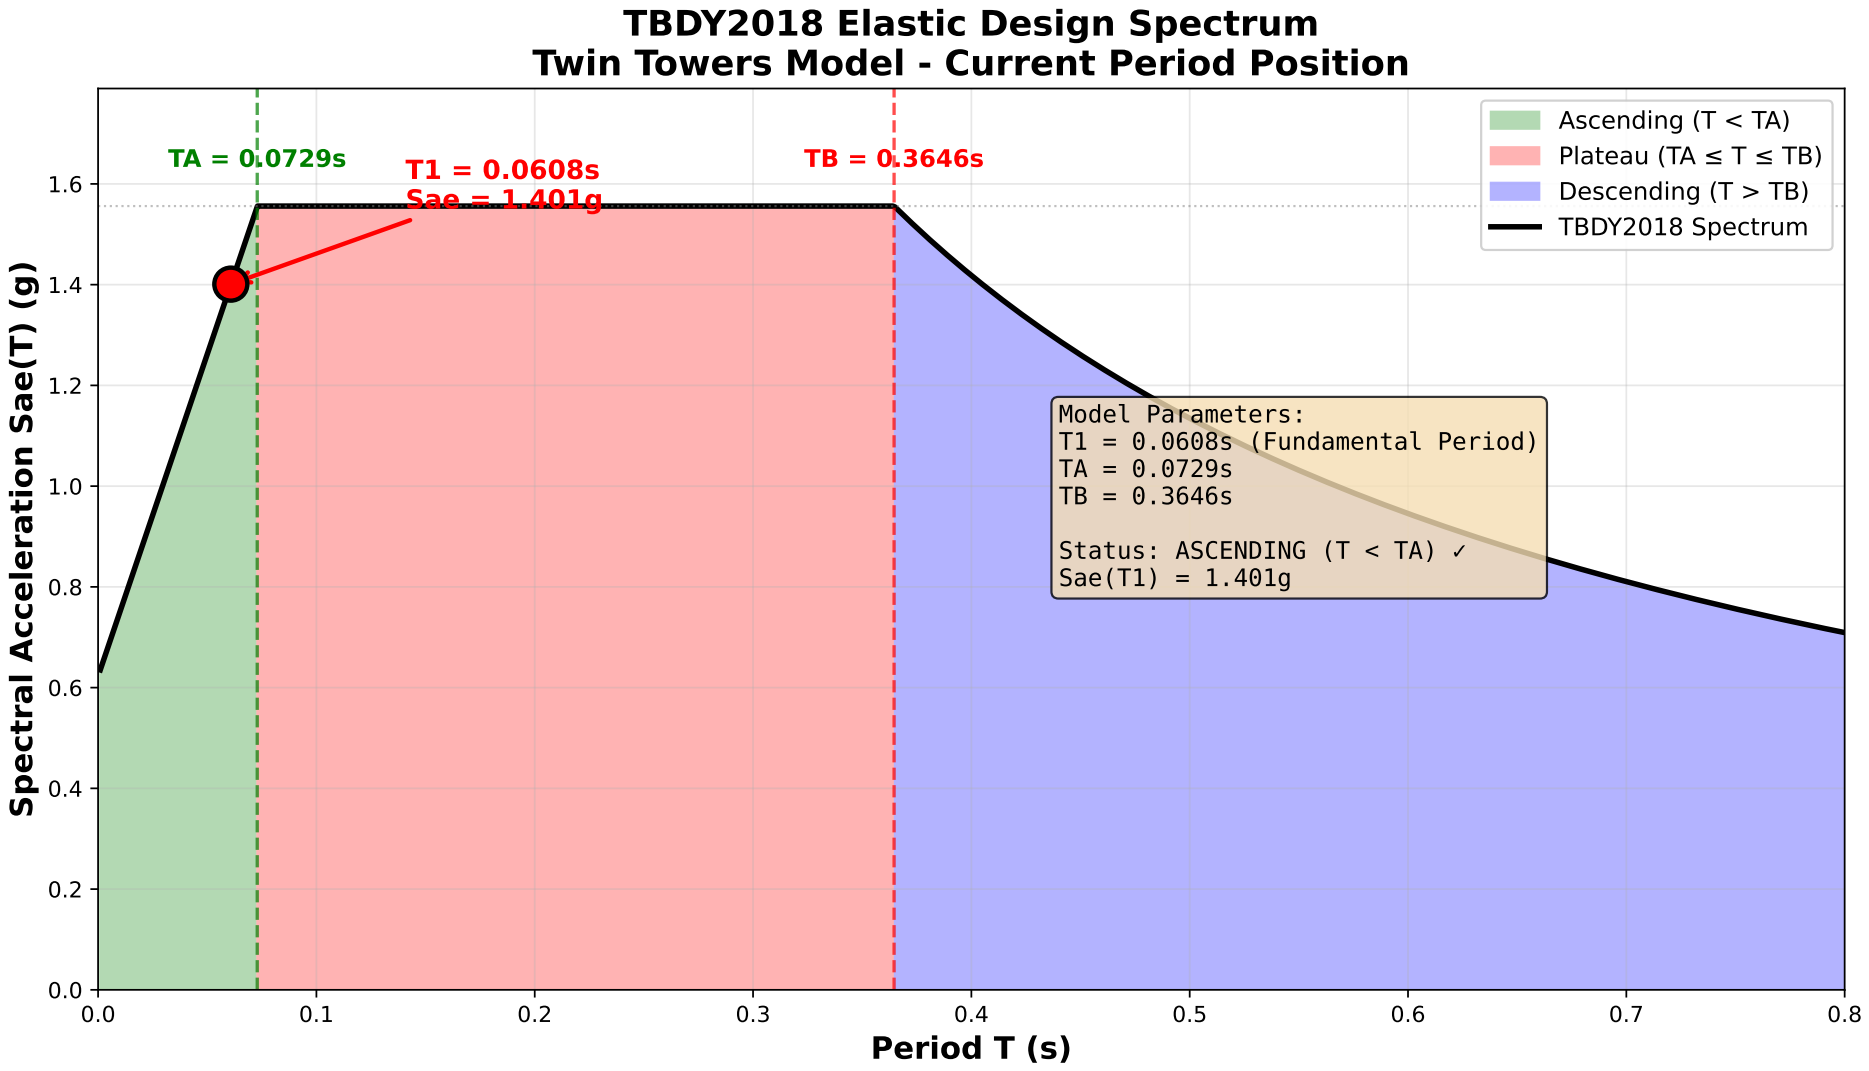
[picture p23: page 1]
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

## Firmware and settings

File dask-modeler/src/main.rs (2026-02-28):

//! Application entry point for the DASK structural modeler.

use std::fs;
use std::path::PathBuf;

use bevy::pbr::{MaterialPlugin, StandardMaterial};
use bevy::picking::prelude::{MeshPickingCamera, MeshPickingPlugin, Pickable};
use bevy::prelude::*;
use bevy_egui::{EguiPlugin, EguiPrimaryContextPass};
use bevy_panorbit_camera::{PanOrbitCamera, PanOrbitCameraPlugin};
use dask_modeler::commands::{AssignRestraintsCommand, MergeNodesCommand, UndoStack};
use dask_modeler::ecs::components::{
    ElementMarker, NodeMarker, NodeZone, StructuralElement, StructuralNode,
};
use dask_modeler::ecs::events::SelectionChangedEvent;
use dask_modeler::ecs::resources::{
    CoordinateInputState, DisplaySettings, DrawingState, ElementTableState, ExportRequest,
    FileDialogState, FileOpenRequest, ModelCatalog, ModelChangeState, ModelDataset, ModelStats,
    NewMaterialDialogState, NewSectionDialogState, NodeMergeState, ProjectResource,
    RestraintDialogState, SectionPlanes, SelectionState, SelectionTypeFilter, SnapSettings,
    ToolMode, TransformOpsState, UiSettings, ViewMode, VisibilityFilter,
};
use dask_modeler::ecs::systems::camera::{MainCamera, apply_view_mode, keyboard_view_presets};
use dask_modeler::ecs::systems::drawing::{
    cancel_drawing_with_escape, draw_snap_and_preview, handle_drawing_clicks,
    handle_edit_shortcuts, sync_tool_mode_to_drawing_state, toggle_continuous_draw,
};
use dask_modeler::ecs::systems::grid::draw_reference_grids;
use dask_modeler::ecs::systems::input::update_cursor_world_position;
use dask_modeler::ecs::systems::picking::handle_element_click_selection;
use dask_modeler::ecs::systems::render::{draw_structural_model, sync_node_visuals};
use dask_modeler::ecs::systems::section_cut::{
    SectionCutMaterial, section_plane_shortcuts, spawn_section_plane_visuals,
    sync_section_cut_materials, update_section_plane_visuals,
};
use dask_modeler::ecs::systems::transform::{
    apply_transform_requests, draw_transform_previews, handle_node_drag_move,
    handle_transform_shortcuts, handle_window_selection,
};
use dask_modeler::io::json_project::{load_project_json, save_project_json};
use dask_modeler::io::matrix_export::{
    export_adjacency_dense_csv, export_adjacency_sparse_csr_csv, export_connectivity_csv,
};
use dask_modeler::io::opensees_export::export_opensees_tcl;
use dask_modeler::model::Project;
use dask_modeler::ui::dialogs::coordinate_input::coordinate_input_dialog_ui;
use dask_modeler::ui::dialogs::new_material::new_material_dialog_ui;
use dask_modeler::ui::dialogs::new_section::new_section_dialog_ui;
use dask_modeler::ui::dialogs::restraint_assignment::restraint_assignment_dialog_ui;
use dask_modeler::ui::element_table::element_table_ui;
use dask_modeler::ui::labels_overlay::labels_overlay_ui;
use dask_modeler::ui::model_tree::model_tree_ui;
use dask_modeler::ui::properties_panel::properties_panel_ui;
use dask_modeler::ui::section_plane_controls::section_plane_controls_ui;
use dask_modeler::ui::section_view::section_view_ui;
use dask_modeler::ui::status_bar::status_bar_ui;
use dask_modeler::ui::theme::apply_ui_theme;
use dask_modeler::ui::toolbar::toolbar_ui;
use log::{error, info};

const DEFAULT_CENTER: Vec3 = Vec3::new(10.0, 8.0, 76.0);
const DEFAULT_EYE: Vec3 = Vec3::new(90.0, 65.0, 110.0);

fn main() {
    App::new()
        .add_plugins(DefaultPlugins)
        .add_plugins(EguiPlugin::default())
        .add_plugins(PanOrbitCameraPlugin)
        .add_plugins(MaterialPlugin::<SectionCutMaterial>::default())
        .add_plugins(MeshPickingPlugin)
        .insert_resource(ToolMode::default())
        .insert_resource(ViewMode::default())
        .insert_resource(SectionPlanes::default())
        .insert_resource(DisplaySettings::default())
        .insert_resource(SnapSettings::default())
        .insert_resource(DrawingState::default())
        .insert_resource(SelectionState::default())
        .insert_resource(CoordinateInputState::default())
        .insert_resource(NewSectionDialogState::default())
        .insert_resource(NewMaterialDialogState::default())
        .insert_resource(RestraintDialogState::default())
        .insert_resource(NodeMergeState::default())
        .insert_resource(UiSettings::default())
        .insert_resource(ElementTableState::default())
        .insert_resource(ModelStats::default())
        .insert_resource(VisibilityFilter::default())
        .insert_resource(ModelCatalog::default())
        .insert_resource(FileDialogState::default())
        .insert_resource(ModelChangeState::default())
        .insert_resource(ProjectResource::default())
        .insert_resource(SelectionTypeFilter::default())
        .insert_resource(TransformOpsState::default())
        .insert_resource(UndoStack::default())
        .add_message::<SelectionChangedEvent>()
        .add_systems(
            Startup,
            (
                setup_scene,
                initialize_model_catalog,
                spawn_section_plane_visuals,
            ),
        )
        .add_systems(
            Update,
            (
                keyboard_view_presets,
                apply_view_mode,
                section_plane_shortcuts,
                update_cursor_world_position,
                handle_transform_shortcuts,
                handle_window_selection,
                handle_element_click_selection,
                handle_node_drag_move,
                apply_transform_requests,
                sync_tool_mode_to_drawing_state,
                toggle_continuous_draw,
                cancel_drawing_with_escape,
                handle_drawing_clicks,
                handle_edit_shortcuts,
                handle_file_menu_actions,
                handle_model_edit_requests,
                load_model_from_file_dialog,
            ),
        )
        .add_systems(
            Update,
            (
                load_selected_model_from_catalog,
                rebuild_model_entities_if_dirty,
                sync_section_cut_materials,
                update_section_plane_visuals,
                draw_reference_grids,
                sync_node_visuals,
                draw_structural_model,
                draw_transform_previews,
                draw_snap_and_preview,
            ),
        )
        .add_systems(
            EguiPrimaryContextPass,
            (
                toolbar_ui,
                model_tree_ui,
                section_plane_controls_ui,
                section_view_ui,
                properties_panel_ui,
                status_bar_ui,
                coordinate_input_dialog_ui,
                new_section_dialog_ui,
                new_material_dialog_ui,
                restraint_assignment_dialog_ui,
                element_table_ui,
                labels_overlay_ui,
                apply_ui_theme,
            ),
        )
        .run();
}

/// Initializes camera and lighting for an empty workspace.
fn setup_scene(mut commands: Commands<'_, '_>) {
    spawn_camera_and_light(&mut commands);
}

fn spawn_camera_and_light(commands: &mut Commands<'_, '_>) {
    let mut pan_orbit = PanOrbitCamera::default();
    pan_orbit.button_orbit = MouseButton::Right;
    pan_orbit.button_pan = MouseButton::Middle;
    pan_orbit.focus = DEFAULT_CENTER;
    pan_orbit.target_focus = DEFAULT_CENTER;
    pan_orbit.radius = Some(DEFAULT_EYE.distance(DEFAULT_CENTER));
    pan_orbit.target_radius = DEFAULT_EYE.distance(DEFAULT_CENTER);

    commands.spawn((
        Camera3d::default(),
        MeshPickingCamera,
        Transform::from_translation(DEFAULT_EYE).looking_at(DEFAULT_CENTER, Vec3::Z),
        MainCamera,
        pan_orbit,
        Name::new("Main Camera"),
    ));

    commands.spawn((
        DirectionalLight {
            shadows_enabled: false,
            illuminance: 20_000.0,
            ..default()
        },
        Transform::from_xyz(50.0, -30.0, 120.0).looking_at(DEFAULT_CENTER, Vec3::Z),
        Name::new("Sun Light"),
    ));
}

fn spawn_node_entities(
    commands: &mut Commands<'_, '_>,
    meshes: &mut Assets<Mesh>,
    node_materials: &mut Assets<StandardMaterial>,
    project: &Project,
    node_size: f32,
) -> std::collections::HashMap<u32, Vec3> {
    let mut node_positions = std::collections::HashMap::with_capacity(project.nodes.len());
    let mesh = meshes.add(Sphere::new(1.0).mesh().uv(12, 8));
    let material = node_materials.add(StandardMaterial {
        base_color: Color::srgb(0.92, 0.92, 0.95),
        unlit: true,
        ..default()
    });

    for node in project.nodes.values() {
        let position = Vec3::new(node.x as f32, node.y as f32, node.z as f32);
        node_positions.insert(node.id, position);
        commands.spawn((
            Mesh3d(mesh.clone()),
            MeshMaterial3d(material.clone()),
            Pickable::IGNORE,
            StructuralNode {
                id: node.id,
                position: node.coords(),
                floor: node.floor,
                zone: NodeZone::from_str(&node.zone),
                restraints: node.restraints,
            },
            NodeMarker,
            Transform::from_translation(position).with_scale(Vec3::splat(node_size.max(0.02))),
            Name::new(format!("Node {}", node.id)),
        ));
    }

    node_positions
}

fn spawn_element_entities(
    commands: &mut Commands<'_, '_>,
    meshes: &mut Assets<Mesh>,
    materials: &mut Assets<SectionCutMaterial>,
    project: &Project,
    node_positions: &std::collections::HashMap<u32, Vec3>,
) {
    for element in project.elements.values() {
        let Some(a) = node_positions.get(&element.node_i).copied() else {
            continue;
        };
        let Some(b) = node_positions.get(&element.node_j).copied() else {
            continue;
        };

        let direction = b - a;
        let length = direction.length();
        if length <= f32::EPSILON {
            continue;
        }

        let midpoint = (a + b) * 0.5;
        let rotation = Quat::from_rotation_arc(Vec3::X, direction.normalize());
        let (size_y, size_z) = section_render_dims(project, element);
        let pick_mesh = meshes.add(Cuboid::new(length, size_y, size_z));
        let pick_material = materials.add(SectionCutMaterial {
            params: dask_modeler::ecs::systems::section_cut::SectionCutUniforms {
                base_color: Vec4::new(1.0, 1.0, 1.0, 0.35),
                plane_xy: Vec4::new(0.0, 0.0, 1.0, 0.0),
                plane_xz: Vec4::new(0.0, 1.0, 0.0, 0.0),
                plane_yz: Vec4::new(1.0, 0.0, 0.0, 0.0),
                flags: Vec4::new(0.0, 0.0, 0.0, 1.0),
            },
            alpha_mode: AlphaMode::Blend,
        });

        commands.spawn((
            Mesh3d(pick_mesh),
            MeshMaterial3d(pick_material),
            Transform::from_translation(midpoint).with_rotation(rotation),
            Pickable::default(),
            StructuralElement {
                id: element.id,
                node_i: element.node_i,
                node_j: element.node_j,
                element_type: element.element_type.clone().into(),
                section_id: element.section_id,
                material_id: element.material_id,
                releases_i: element.releases_i,
                releases_j: element.releases_j,
            },
            ElementMarker,
            Name::new(format!("Element {}", element.id)),
        ));
    }
}

fn section_render_dims(
    project: &Project,
    element: &dask_modeler::model::ElementData,
) -> (f32, f32) {
    let Some(section_id) = element.section_id else {
        return (0.08, 0.08);
    };
    let Some(section) = project.sections.get(&section_id) else {
        return (0.08, 0.08);
    };

    match &section.shape {
        dask_modeler::model::SectionShape::Rectangular { width, height } => {
            ((*width).max(0.08) as f32, (*height).max(0.08) as f32)
        }
        dask_modeler::model::SectionShape::IBeam {
            flange_w,
            flange_t: _,
            web_h,
            web_t: _,
        } => (
            (*flange_w).max(0.08) as f32,
            (*web_h + 2.0).max(0.08) as f32,
        ),
        dask_modeler::model::SectionShape::Circular { diameter } => {
            ((*diameter).max(0.08) as f32, (*diameter).max(0.08) as f32)
        }
        dask_modeler::model::SectionShape::Pipe {
            outer_d,
            inner_d: _,
        } => ((*outer_d).max(0.08) as f32, (*outer_d).max(0.08) as f32),
        dask_modeler::model::SectionShape::LAngle {
            leg_a,
            leg_b,
            thickness: _,
        } => ((*leg_a).max(0.08) as f32, (*leg_b).max(0.08) as f32),
    }
}

/// Scans `data/` for position/connectivity dataset pairs and populates model catalog.
fn initialize_model_catalog(mut catalog: ResMut<'_, ModelCatalog>) {
    let data_dir = PathBuf::from(env!("CARGO_MANIFEST_DIR"))
        .join("..")
        .join("data");
    catalog.datasets = discover_datasets(&data_dir);
    if let Some(base_index) = catalog.datasets.iter().position(|d| d.label == "Base") {
        catalog.selected_index = base_index;
    } else {
        catalog.selected_index = 0;
    }
    catalog.load_requested = false;
}

/// Loads user-selected dataset from toolbar model opener.
fn load_selected_model_from_catalog(
    mut catalog: ResMut<'_, ModelCatalog>,
    mut file_dialog: ResMut<'_, FileDialogState>,
    mut project_res: ResMut<'_, ProjectResource>,
    mut undo_stack: ResMut<'_, UndoStack>,
    mut model_change: ResMut<'_, ModelChangeState>,
    mut selection: ResMut<'_, SelectionState>,
    mut drawing_state: ResMut<'_, DrawingState>,
) {
    if !catalog.load_requested {
        return;
    }
    catalog.load_requested = false;

    let Some(dataset) = catalog.datasets.get(catalog.selected_index) else {
        return;
    };

    match Project::from_csv(&dataset.position_csv, &dataset.connectivity_csv) {
        Ok(project) => {
            info!(
                "Loaded dataset {} with {} nodes and {} elements",
                dataset.label,
                project.nodes.len(),
                project.elements.len()
            );
            apply_loaded_project(
                project,
                &mut project_res,
                &mut undo_stack,
                &mut selection,
                &mut drawing_state,
                &mut model_change,
            );
            file_dialog.active_json_path = None;
        }
        Err(err) => {
            error!(
                "Failed to load dataset {}: {} / {} ({err:#})",
                dataset.label,
                dataset.position_csv.display(),
                dataset.connectivity_csv.display()
            );
        }
    }
}

/// Loads model files selected through the native File/Open dialog.
fn load_model_from_file_dialog(
    mut file_dialog: ResMut<'_, FileDialogState>,
    mut project_res: ResMut<'_, ProjectResource>,
    mut undo_stack: ResMut<'_, UndoStack>,
    mut model_change: ResMut<'_, ModelChangeState>,
    mut selection: ResMut<'_, SelectionState>,
    mut drawing_state: ResMut<'_, DrawingState>,
) {
    let Some(request) = file_dialog.pending_open.take() else {
        return;
    };

    let result = match &request {
        FileOpenRequest::CsvPair {
            position_csv,
            connectivity_csv,
        } => Project::from_csv(position_csv, connectivity_csv),
        FileOpenRequest::JsonProject { path } => load_project_json(path),
    };

    match result {
        Ok(project) => {
            info!(
                "Loaded model with {} nodes and {} elements from File/Open",
                project.nodes.len(),
                project.elements.len()
            );
            apply_loaded_project(
                project,
                &mut project_res,
                &mut undo_stack,
                &mut selection,
                &mut drawing_state,
                &mut model_change,
            );
            match request {
                FileOpenRequest::CsvPair {
                    position_csv,
                    connectivity_csv: _,
                } => {
                    file_dialog.active_json_path = None;
                    file_dialog.last_directory = position_csv.parent().map(PathBuf::from);
                }
                FileOpenRequest::JsonProject { path } => {
                    file_dialog.active_json_path = Some(path.clone());
                    file_dialog.last_directory = path.parent().map(PathBuf::from);
                }
            }
        }
        Err(err) => match request {
            FileOpenRequest::CsvPair {
                position_csv,
                connectivity_csv,
            } => error!(
                "Failed to load csv pair {} / {} ({err:#})",
                position_csv.display(),
                connectivity_csv.display()
            ),
            FileOpenRequest::JsonProject { path } => {
                error!("Failed to load json project {} ({err:#})", path.display())
            }
        },
    }
}

/// Handles file menu save/new requests.
fn handle_file_menu_actions(
    mut file_dialog: ResMut<'_, FileDialogState>,
    mut project_res: ResMut<'_, ProjectResource>,
    mut undo_stack: ResMut<'_, UndoStack>,
    mut model_change: ResMut<'_, ModelChangeState>,
    mut selection: ResMut<'_, SelectionState>,
    mut drawing_state: ResMut<'_, DrawingState>,
) {
    if file_dialog.new_model_requested {
        file_dialog.new_model_requested = false;
        apply_loaded_project(
            Project::new("Untitled Model"),
            &mut project_res,
            &mut undo_stack,
            &mut selection,
            &mut drawing_state,
            &mut model_change,
        );
        file_dialog.active_json_path = None;
        info!("Started new empty model");
    }

    let Some(path) = file_dialog.pending_save.take() else {
        if let Some(export_request) = file_dialog.pending_export.take() {
            match export_request {
                ExportRequest::ConnectivityCsv { path } => {
                    if let Err(err) = export_connectivity_csv(&project_res.project, &path) {
                        error!(
                            "Failed to export connectivity csv {} ({err:#})",
                            path.display()
                        );
                    } else {
                        info!("Exported connectivity csv to {}", path.display());
                    }
                }
                ExportRequest::AdjacencyDenseCsv { path } => {
                    if let Err(err) = export_adjacency_dense_csv(&project_res.project, &path) {
                        error!(
                            "Failed to export dense adjacency csv {} ({err:#})",
                            path.display()
                        );
                    } else {
                        info!("Exported dense adjacency csv to {}", path.display());
                    }
                }
                ExportRequest::AdjacencySparseCsrCsv { path } => {
                    if let Err(err) = export_adjacency_sparse_csr_csv(&project_res.project, &path) {
                        error!(
                            "Failed to export sparse adjacency csv {} ({err:#})",
                            path.display()
                        );
                    } else {
                        info!("Exported sparse adjacency csv to {}", path.display());
                    }
                }
                ExportRequest::OpenSeesTcl { path } => {
                    if let Err(err) = export_opensees_tcl(&project_res.project, &path) {
                        error!("Failed to export OpenSees TCL {} ({err:#})", path.display());
                    } else {
                        info!("Exported OpenSees TCL to {}", path.display());
                    }
                }
            }
        }
        return;
    };

    match save_project_json(&project_res.project, &path) {
        Ok(()) => {
            file_dialog.active_json_path = Some(path.clone());
            file_dialog.last_directory = path.parent().map(PathBuf::from);
            push_recent_json(&mut file_dialog, path);
            info!("Saved project json");
        }
        Err(err) => error!("Failed to save project json ({err:#})"),
    }
}
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

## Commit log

2026-02-07 DASK 2026 Twin Towers - Structural Analysis
    [BinaTasarimi_2025_YerHareketleri(KYH2_KYH3).xlsx, adjacency_matrix.csv, afad_spectrum_dd2.tsv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]
2026-02-08 feat: report analysis compilation
    [peak_response.csv, time_history_xi005.csv, time_history_xi010.csv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]
2026-02-08 Add damage assessment and floor data extraction scripts for DASK 2026 analysis
    [floor_summary.csv]
2026-02-08 Created `fragility_analysis.py` for basic fragility analysis following FEMA P-58 methodology, calculating DCR, bending stress, and shear stress for each ground motion.
2026-02-08 Add V10
    [modal_periods_calibrated.tsv, modal_results_v10.csv, modal_results_v10_calibrated.csv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]
2026-02-09 Add V10 scripts for eccentricity and analysis
    [modal_results_v10.csv]
2026-02-09 sap analysis
    [joint_coordinates.csv, pushover_X_curve.csv, pushover_Y_curve.csv]
2026-02-09 add sap analysis results and report
    [all_envelopes.csv, joint_coordinates.csv, th_summary.csv]
2026-02-09 update the report and analysis
    [21.01.dwg, 21.01_V2.dwg, DASK2026_Alan_Hesabi.xlsx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]
2026-02-09 add blender renders and report
    [twin_towers_v10_a4.blend]
